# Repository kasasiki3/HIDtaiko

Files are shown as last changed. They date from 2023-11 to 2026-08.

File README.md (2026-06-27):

# HIDtaiko 
#### 低価格で高性能なおうち太鼓プロジェクト
#### HIDtaikoでは[基盤](drumhead/readme_drumhead.md)、[接続器](HIDtaiko_connector_rp2040/rp2040readme.md)の設計を行っています。

[English README](README_EN.md)

 
 
# ◇readme構造
<pre>
.
└── README.md(メイン)
    ├── rp2040readme.md(RP2040接続器の組み立て方、詳細)
    ├── readme_drumhead.md(基盤、詳細)

</pre>

# ◇接続器

> ## [→ RP2040接続器 組み立てガイド](HIDtaiko_connector_rp2040/rp2040readme.md)
> **最新・最安・最高性能のおすすめモデル**（最安800円〜、簡単なはんだ付けのみ）

## 各接続器の比較表
| 項目| 1.2接続器|1.3接続器|2.0接続器| [RP2040接続器](HIDtaiko_connector_rp2040/rp2040readme.md)|
|-----|---|---|---|-----|
| 対応デバイス | PC, Switch | PC| PC, Switch| PC,(switchに対応予定) |
| 感度変更方法 |感度変更サイトで変更可能| 感度変更サイトで変更可能 | 接続器単体で変更可能 | 感度変更サイトで変更可能 |
| ファームウェア | Arduino IDE| Arduino IDE|Arduino IDE| Pico SDK|
| 回路 | 簡易的な1MΩ抵抗| 簡易的な1MΩ抵抗| オペアンプによる信号の増幅| ショットキーバリアダイオードクランプ回路|
| 改造のしやすさ | 簡単| 簡単| 簡単| 難しい|
| 制作難易度 | 中〜高（Arduinoの知識が必要）| 中〜高（Arduinoの知識が必要）| 中〜高（Arduinoの知識が必要）| 低（簡単なはんだ付けのみでOK|
| 制作費用 | 最低構成1500円程度| 最低構成1500円程度| 最低構成2200円程度|最安800円程度|
| 補足 | Switchで使いたい人におすすめ|-|※原因不明の無反応が発生することあり| ※最も新しく、性能も最も高いおすすめモデル |
| プレイ動画 |[動画を見る](https://www.youtube.com/watch?v=cY1Ix29XORo)| [動画を見る](https://www.youtube.com/watch?v=Z8ZBOPpMMD8) | [動画を見る](https://www.youtube.com/watch?v=VVSo0jgkqcQ)| [動画を見る](https://www.youtube.com/watch?v=wMSDLN9h2Co)|

# ◇感度変更サイト

**[→ 感度変更サイトを開く](https://kasasiki3.github.io/HIDtaiko/v12.html)**（Chrome / Edge のみ対応）

接続器を PC に繋いだままブラウザから感度・ディレイを調整できます。V1.1（RP2040）・V1.2 に対応。

## 仕組み

```
ピエゾ → ADC（アナログ読み取り）→ 差分検出 → 閾値判定 → キー入力
```

ピエゾが振動すると電圧が変化します。マイコンは直前サンプルとの差分（デルタ）を計算し、設定した閾値（感度）を超えたときにキー入力を発生させます。

誤検出を防ぐためのタイマー（Delay）も持っており、入力後の一定時間は同センサーや隣接センサーからの入力を無視します。

| パラメータ | 役割 |
|---|---|
| 感度（Sensitivity） | デルタがこの値を超えると入力。値が大きいほど感度が低い |
| Adelay | 同センサーの再入力クールダウン |
| Bdelay | 面（ドン）共有クールダウン |
| Cdelay | 縁（カッ）共有クールダウン |
| Ddelay | 面打後に縁を、縁打後に面を無視する時間 |

# ◇[基盤の作り方](drumhead/readme_drumhead.md)
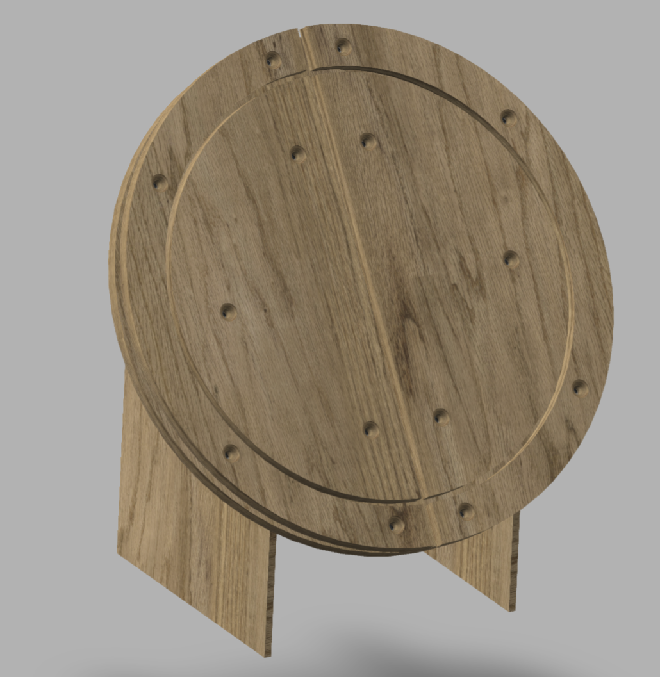
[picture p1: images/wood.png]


## webサイトで基盤のデザインを確認できます:[基盤3Dデータ](https://a360.co/4iZLSSL)

## 基盤の制作方法→記事:[zeen](https://zenn.dev/kasashiki/articles/7bf286b8120f90) 動画:[youtube](https://www.youtube.com/watch?v=5O0MgKzX0PY)

## 特徴
| 項目 | 内容 |
|---|---|
| AC基盤との互換性 | 無 |
| 鉄板・スポンジ・樽| 使用できません |
| 対応面 | AC面・太鼓フォース面|
| 制作所要時間 | 約2〜3時間 |

# ◇センサ
## センサの比較
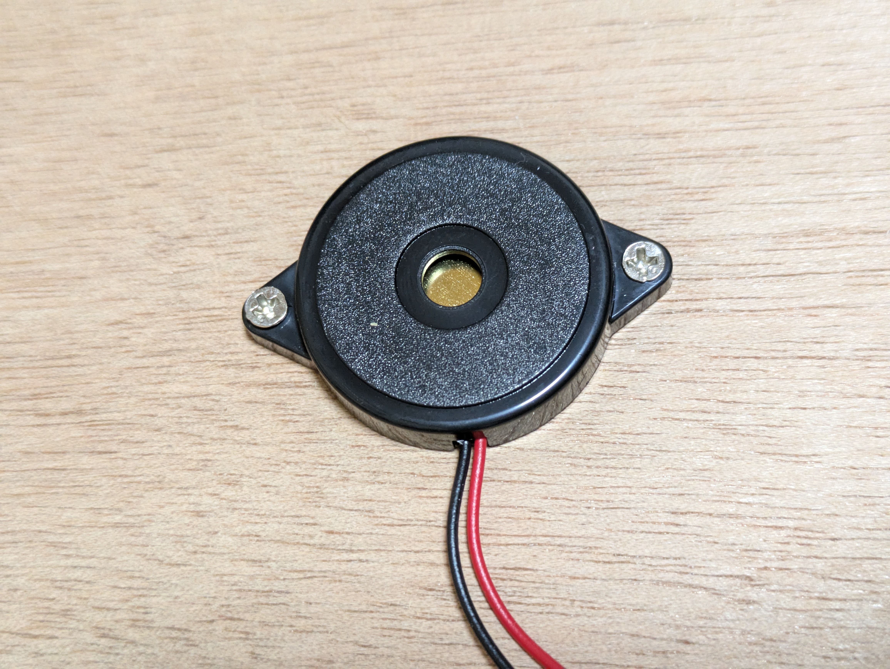
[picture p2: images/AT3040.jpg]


GSS-4SAとAT3040どちらもしっかりと固定することで弱い力でも反応します。しかし、GSS-4SAの方が性能が良いです。設定に余裕が生まれます。価格にかなり差があるため、最初はAT3040センサを購入することをお勧めします。

### [センサ組み立てガイド](drumhead/sensor.md)

# 質問はXのDMにお願いします。
[lit.link](https://lit.link/kasashiki)

## License
*** by kasashiki is licensed under the Apache License, Version2.0

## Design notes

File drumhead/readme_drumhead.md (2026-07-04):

　画像の寸法でベニヤ板をカットし、各ねじを用い組み立てます。組み立ての詳細は[youtube](https://www.youtube.com/watch?v=5O0MgKzX0PY)または[記事(zeen)](https://zenn.dev/kasashiki/articles/7bf286b8120f90)を参照してください。また、販売も行っています。
# 部品
#### ※ラワンベニヤ以外の部品に関してはモノタロウでの購入がおすすめです。
| 部品 | 数量 | 品番|
| ---- | ---- | ---- |
| 防振ゴム | 14 |VD2-2015M6|
| M6ネジ | 14 | [M6L16](https://www.monotaro.com/p/0550/8946/)|
| M6ナット |14 |適当(ネジピッチに注意)|
| M6ワッシャー | 14 |適当|
|ラワンベニヤ | 12mm | ホームセンターなど |  

# 図面
　[A4用紙4を用いた実寸設計図](https://github.com/kasasiki3/HIDtaiko/tree/master/drumhead/fullsizeprint)それぞれのファイルを2枚づつ印刷し、透明なテープで張り合わせてください。


##### 上板の寸法
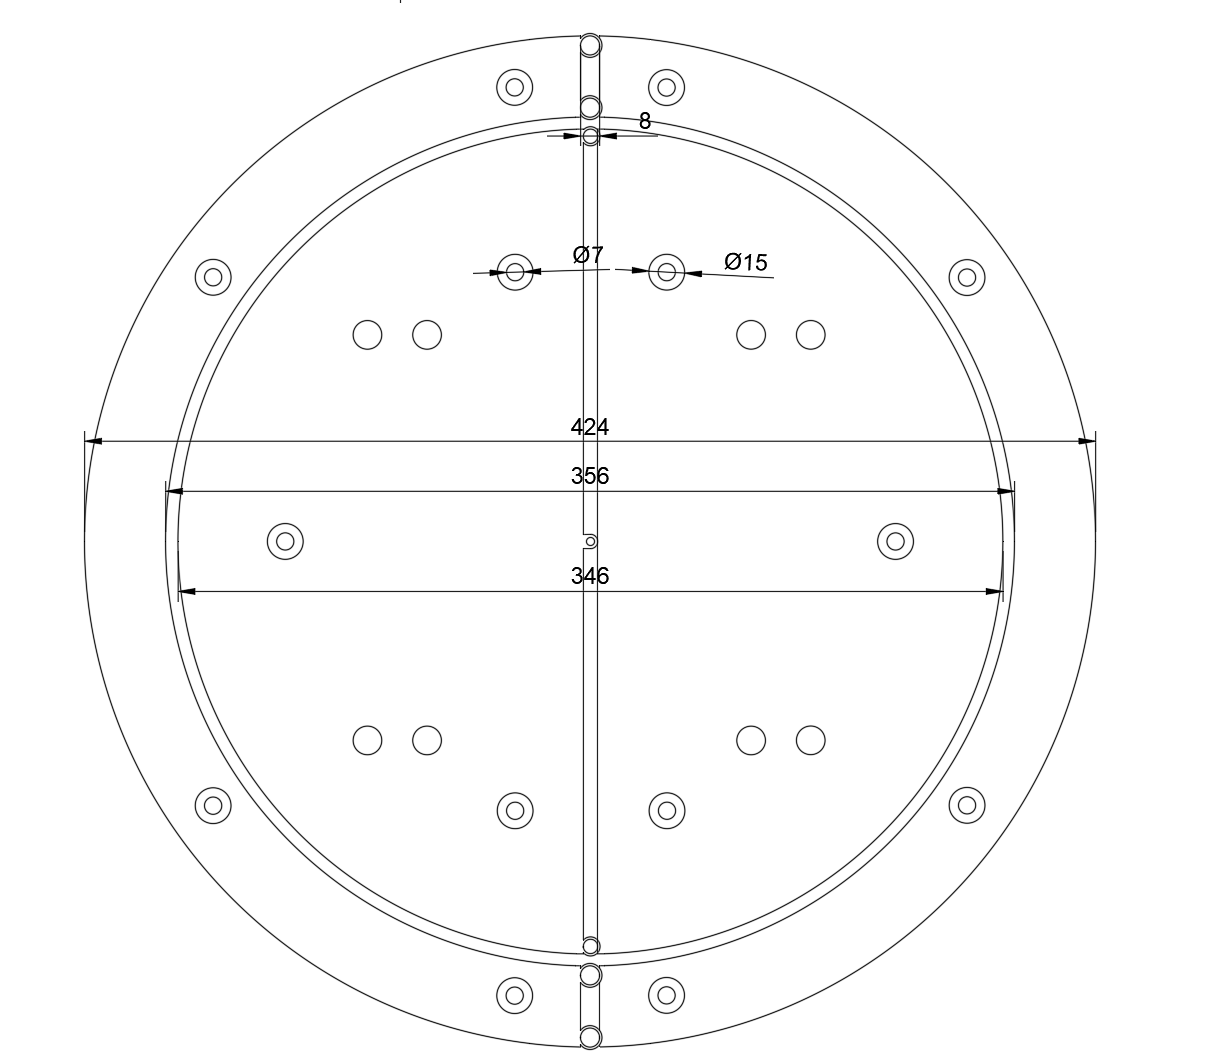
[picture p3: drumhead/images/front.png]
 

 ##### 下板の寸法
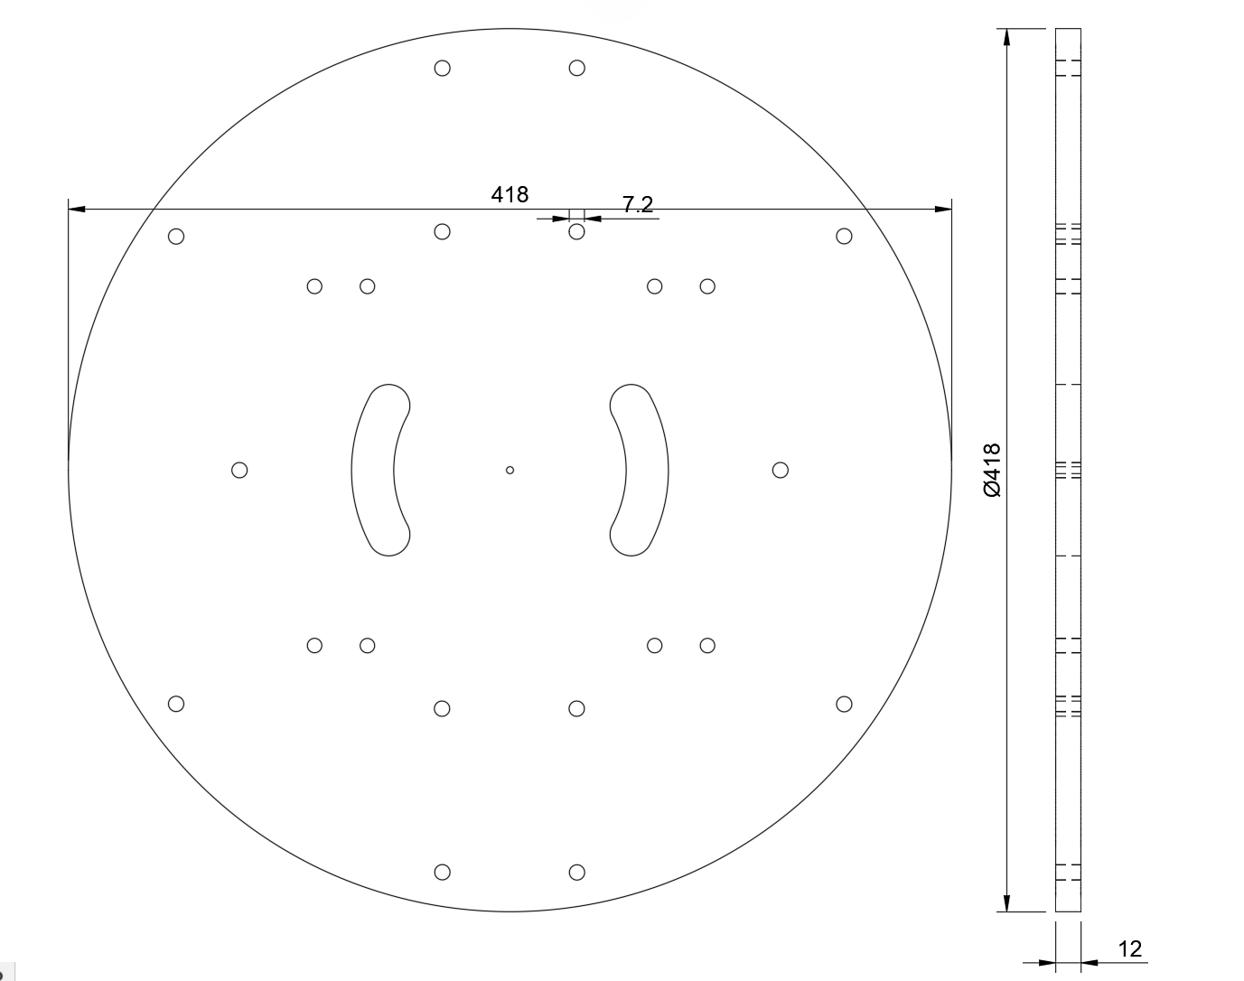
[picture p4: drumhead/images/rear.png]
 

 ##### 足の寸法
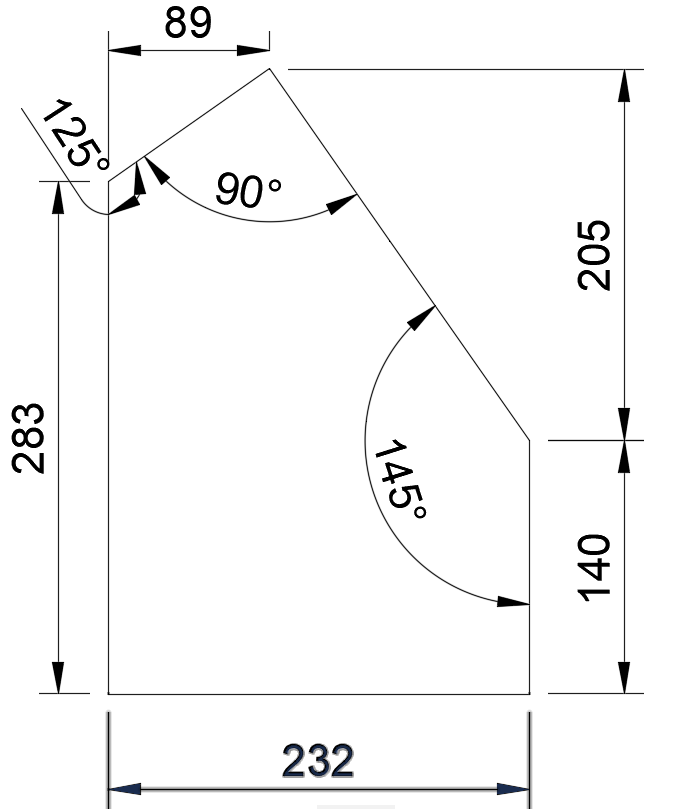
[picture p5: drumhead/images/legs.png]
 

# 3Dプリントパーツ、道具

 ### [面、縁高さ調整用スペーサー(3Dプリント)](spacer) 0.2mm,0.4mm,0.6mm
 
印刷ピッチ0.1～0.2mm、PLAなどで印刷してください。ゴムネジに挟み使用します。

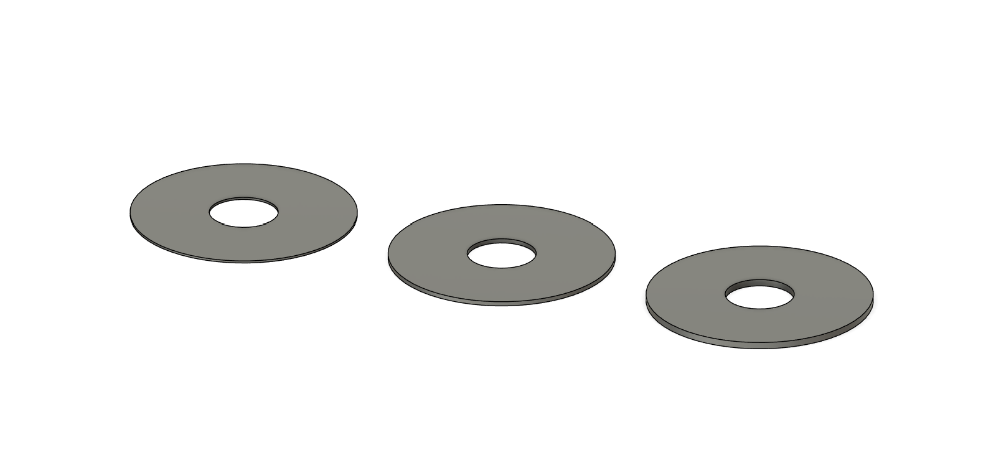
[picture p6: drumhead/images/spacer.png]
  

### [AT3040sensor固定用パーツ(3Dプリント)](AT3040sensor_look)

M3L10ネジを用いて固定します。PLAなどで印刷してください。

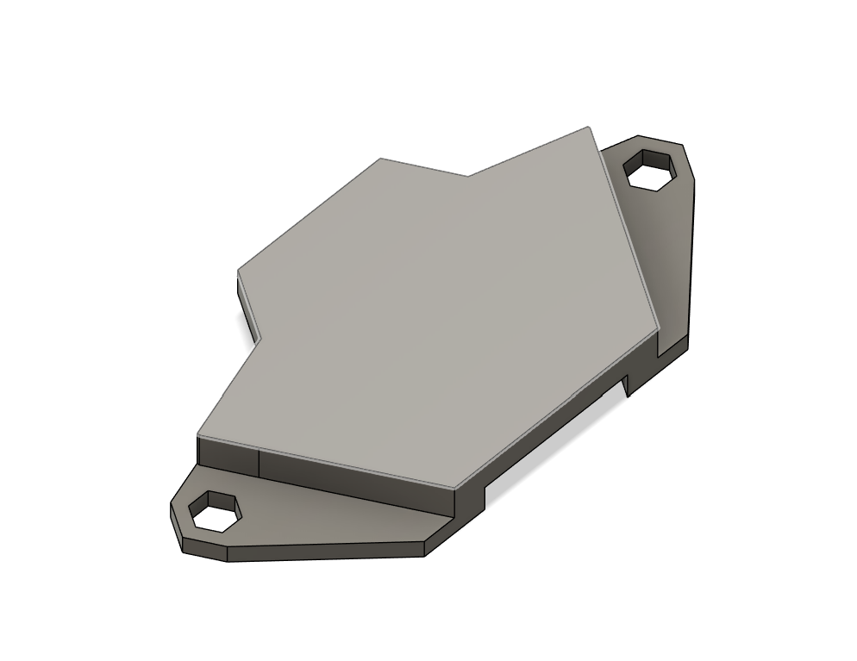
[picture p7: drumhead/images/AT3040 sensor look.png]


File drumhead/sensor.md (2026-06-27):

# 使用するパーツ

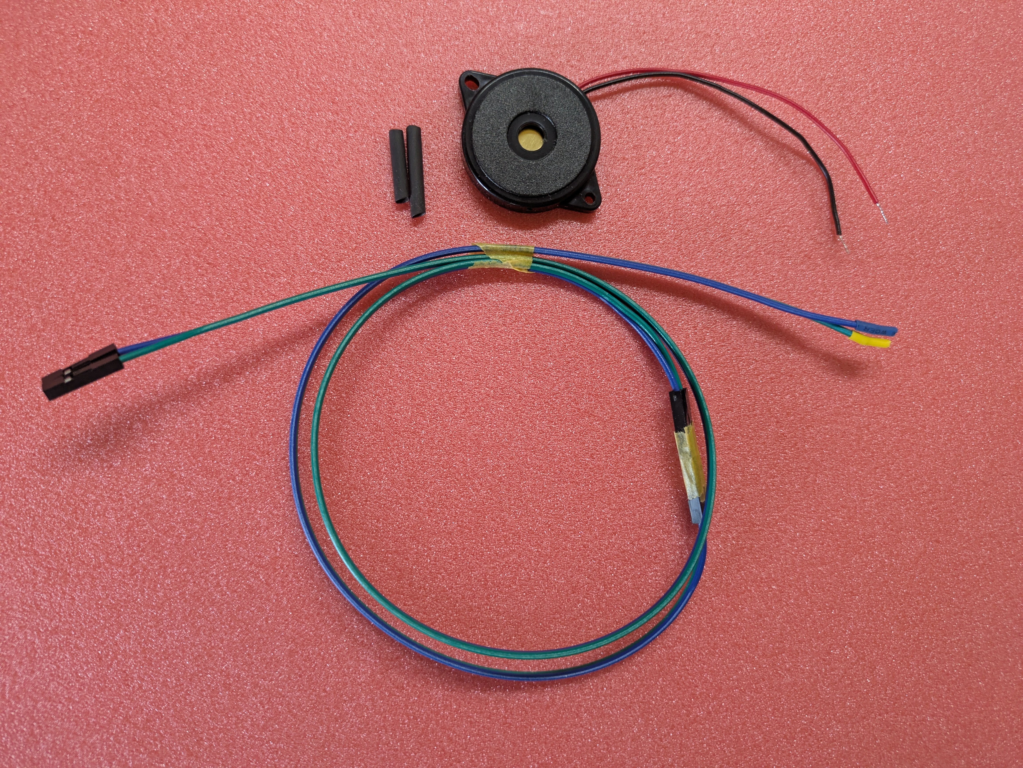
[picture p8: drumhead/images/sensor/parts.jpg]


| 名称 | リンク | 個数 | 合計 |
|---|---|---|---|
| AT3040（センサ） | [aliexpress](https://ja.aliexpress.com/item/1005007327162214.html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) | 5個 | 343円 |
| ケーブル | [aliexpress](https://ja.aliexpress.com/item/1005005364298980.html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) | 1セット | 390円 |
| 熱収縮チューブ(2.5mm)|[aliexpress](https://ja.aliexpress.com/item/1005008597528002.html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)|1|300円|
|固定用M2ネジ|[amazon](https://www.amazon.co.jp/dp/B00AXVBDSO?ref_=ppx_hzsearch_conn_dt_b_fed_asin_title_3)|8本|700円|

# 使用した道具

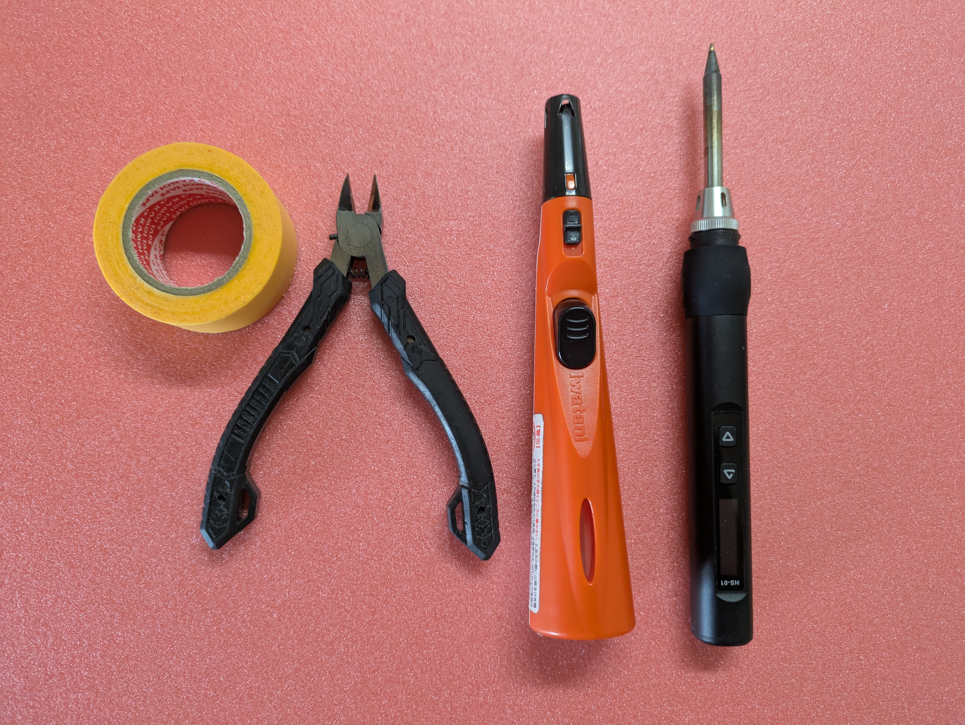
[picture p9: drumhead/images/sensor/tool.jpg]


#### ・はんだごて
#### ・ライター
#### ・ニッパー
#### ・塗装用マスキングテープ

# センサ制作手順

## 1.ケーブルを組み合わせ任意の長さのケーブルを作る

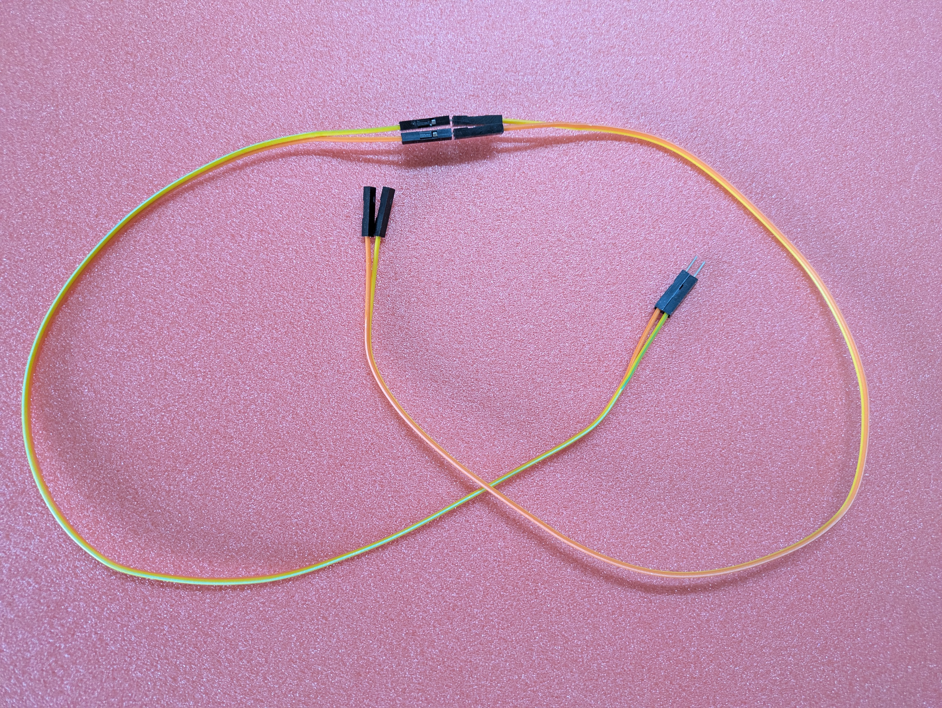
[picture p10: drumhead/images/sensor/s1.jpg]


## 2.接続部を任意の長さで固定する

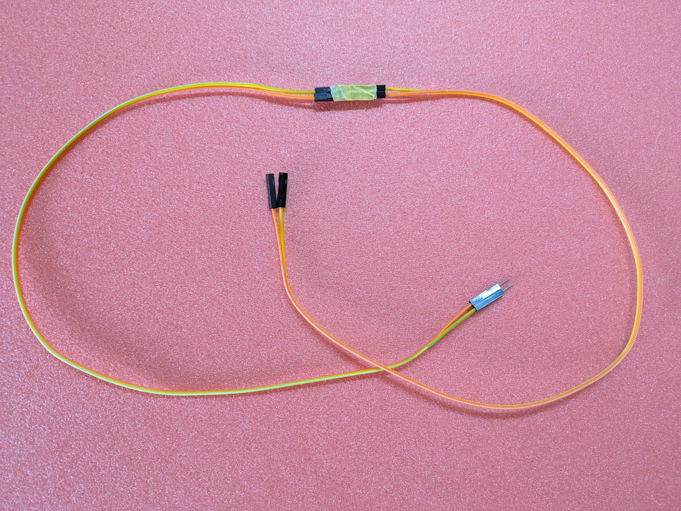
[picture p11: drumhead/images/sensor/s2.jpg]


## 3.オス端子をニッパーで切断する

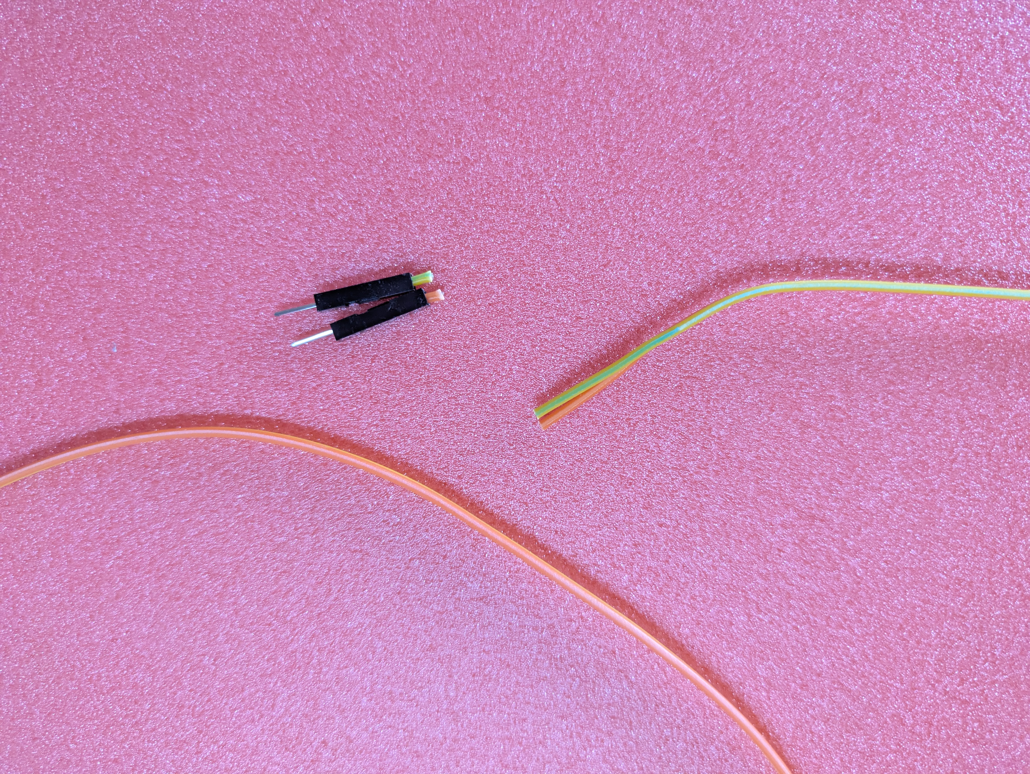
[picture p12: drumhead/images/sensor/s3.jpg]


## 4.ケーブルを剥く(5mm)

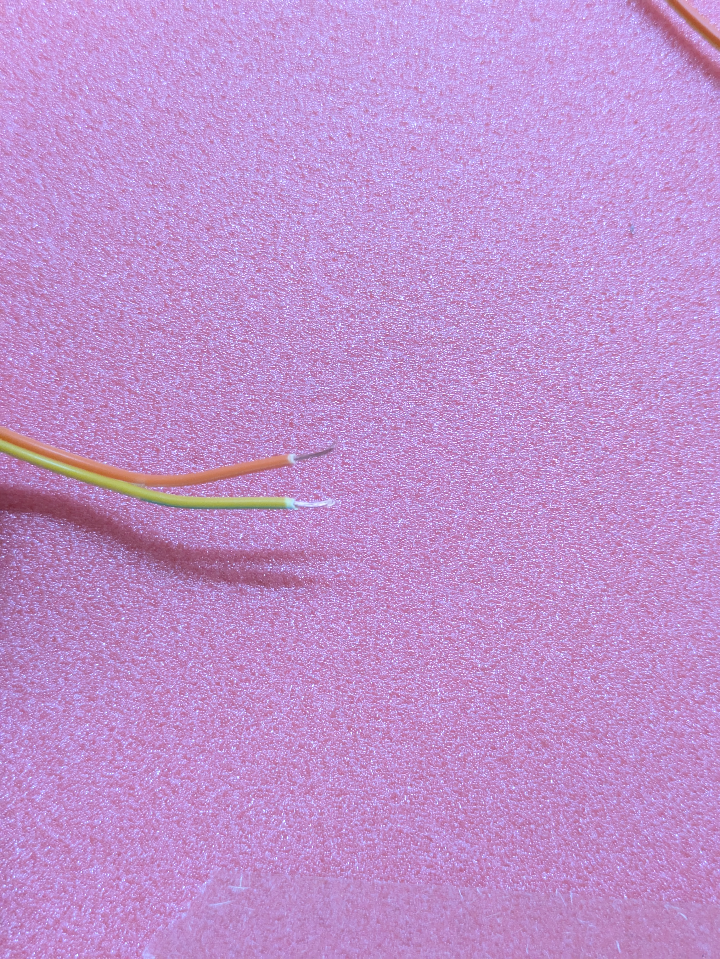
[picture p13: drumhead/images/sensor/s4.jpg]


## 5.露出した銅線に予備ハンダを行う

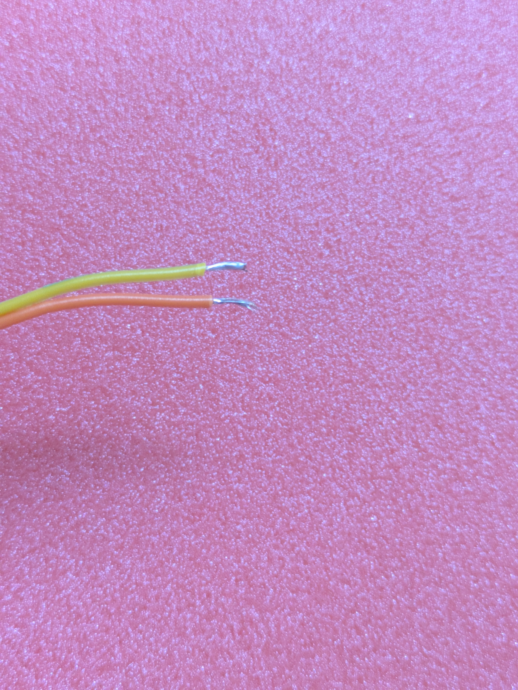
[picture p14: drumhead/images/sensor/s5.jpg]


## 6.センサのケーブルに熱収縮チューブを通す

※熱収縮チューブは10mmにカットしてください。

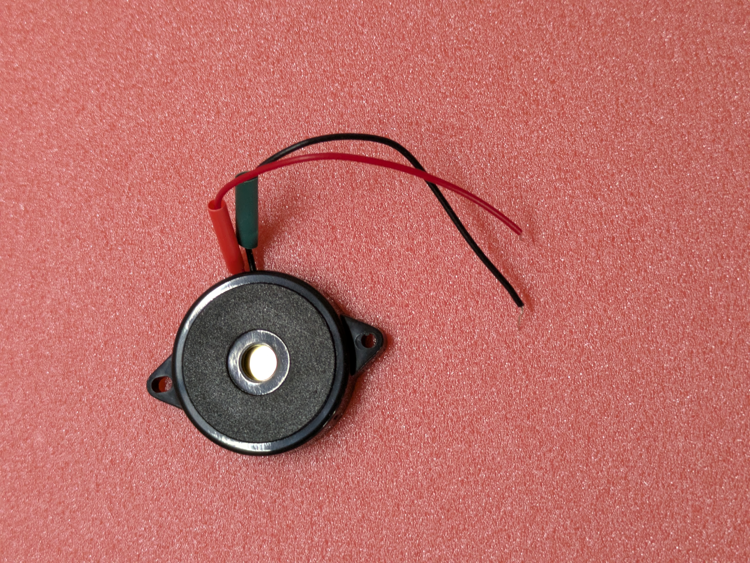
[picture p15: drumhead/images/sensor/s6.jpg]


## 7.ケーブルとセンサをはんだ付けし、しっかりと繋げる

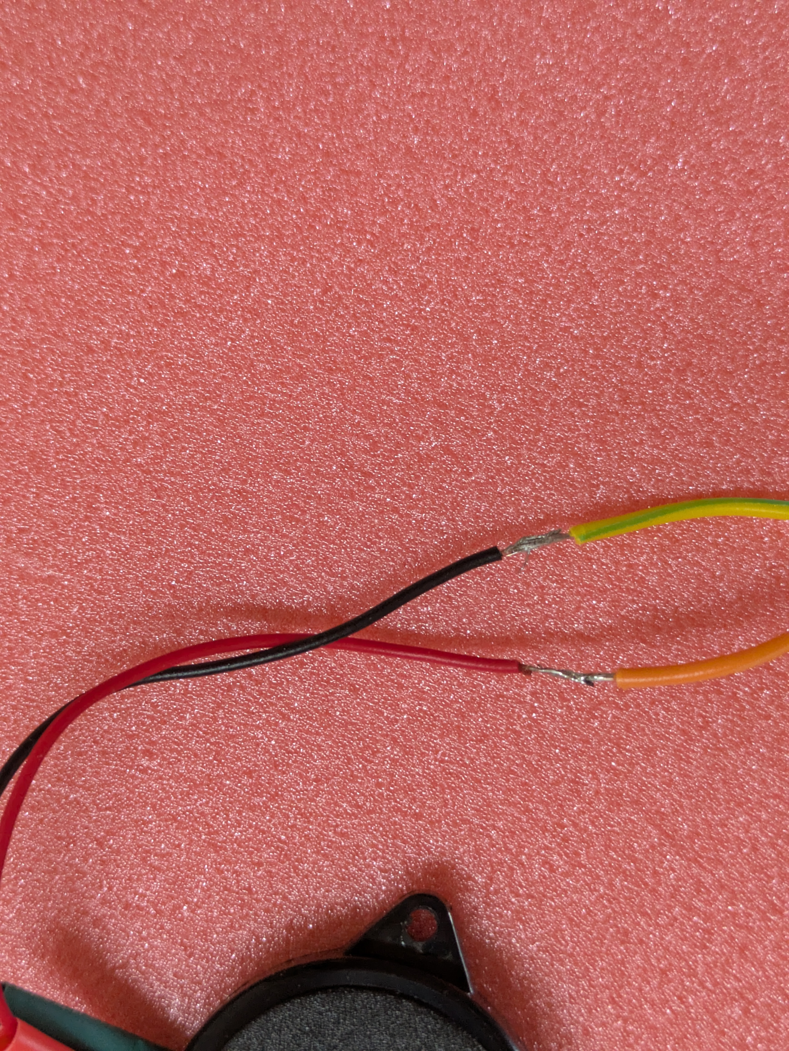
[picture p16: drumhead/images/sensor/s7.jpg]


## 8.熱収縮チューブを加熱し、銅線を保護する

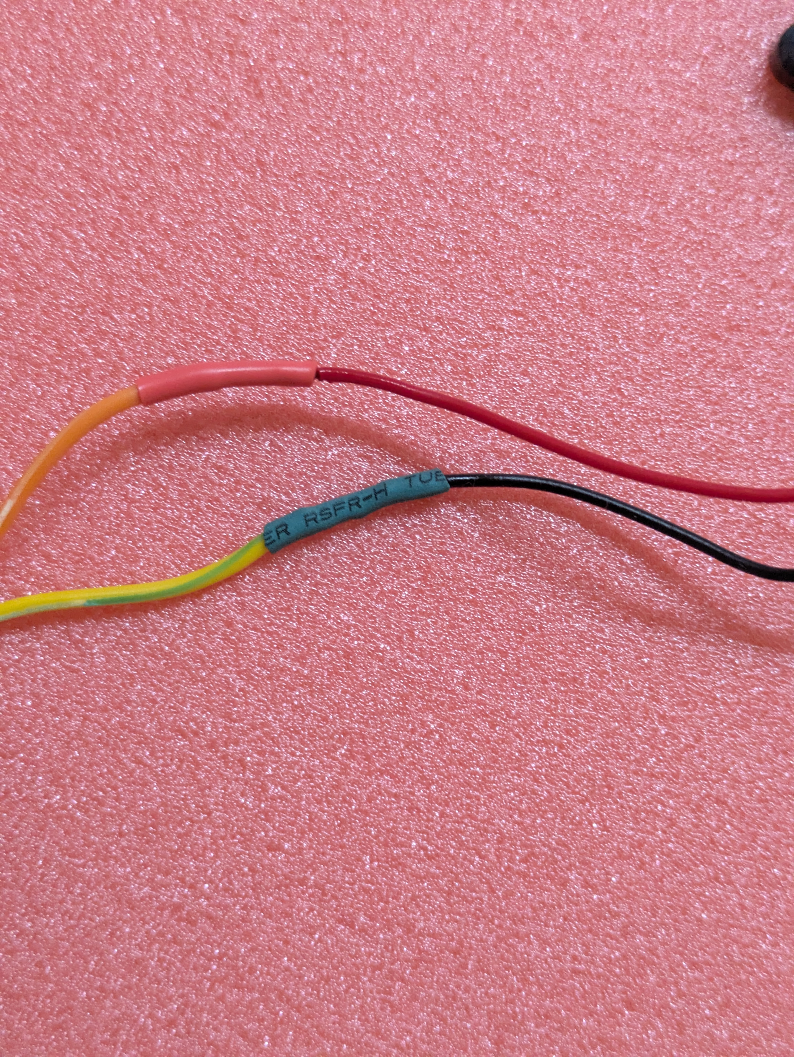
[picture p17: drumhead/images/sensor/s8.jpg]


## 9.この作業を4本分行い、完成

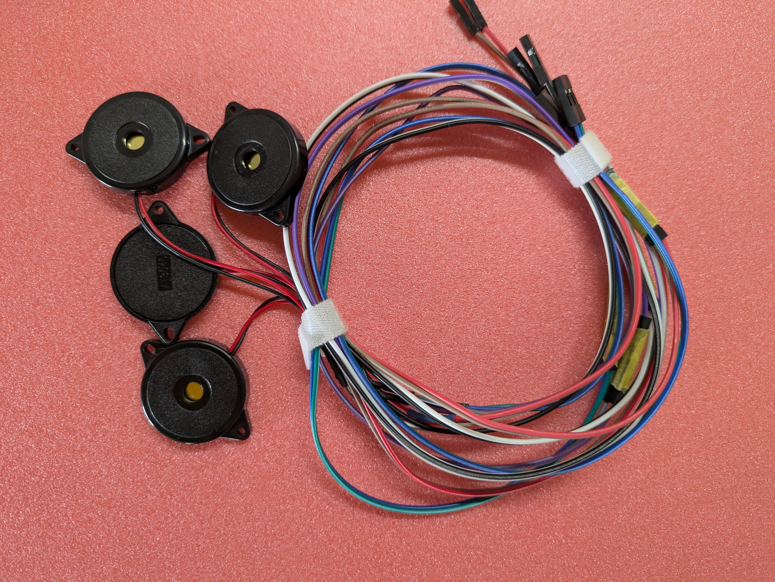
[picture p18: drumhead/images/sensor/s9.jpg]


# 補足

#### ・GSS-4SA（ACセンサ）でも手順は同様です。
#### ・センサの赤いケーブルが＋です。ケーブルの色は以下の画像に合わせることをお勧めします。

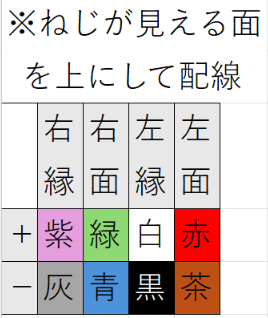
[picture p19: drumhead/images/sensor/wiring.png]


### [AT3040sensor固定用パーツ(3Dプリント)](drumhead/AT3040sensor_look)
センサ固定の際に、こちらを用いることでより確実な固定が可能です。
M3L10ネジを用います。PLAなどで印刷してください。



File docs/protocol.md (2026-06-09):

# HIDtaiko シリアルプロトコル仕様

バージョン: v1.2（ステートレス方式）

---

## 通信方式

- USB CDC シリアル（baud rate: 9600）
- 改行コード: `\n`
- 全コマンドはテキスト形式
- デバイスは全コマンドに対して必ず `OK\n` で応答する

---

## コマンド一覧

### 感度送信 `SENS`

```
JS → device : SENS:0=<v>:1=<v>:2=<v>:3=<v>:4=<v>:5=<v>:6=<v>:7=<v>:8=<v>\n
device → JS : OK\n
```

インデックス対応:

| index | 意味 |
|---|---|
| 0 | 左縁 感度 |
| 1 | 左面 感度 |
| 2 | 右面 感度 |
| 3 | 右縁 感度 |
| 4 | 面入力後の次の入力受付時間 (B) |
| 5 | 縁の入力受付時間 (C) |
| 6 | 面入力時に縁を無視する時間 (D) |
| 7 | シミュレーター用入力制限 (H) |
| 8 | 単体入力受付時間 (A) |

例:
```
SENS:0=80:1=160:2=160:3=80:4=30:5=12:6=35:7=0:8=0
OK
```

---

### 感度要求 `GETS`

```
JS → device : GETS\n
device → JS : 0:<v>\n
              1:<v>\n
              ...
              8:<v>\n
              OK\n
```

例:
```
GETS
0:80
1:160
2:160
3:80
4:30
5:12
6:35
7:0
8:0
OK
```

---

### キー配置送信 `KEY`

```
JS → device : KEY:0=<code>:1=<code>:2=<code>:3=<code>\n
device → JS : OK\n
```

インデックス対応:

| index | 意味 |
|---|---|
| 0 | 左縁 キー |
| 1 | 左面 キー |
| 2 | 右面 キー |
| 3 | 右縁 キー |

値は HID キーコード（例: D=0x07, F=0x09, J=0x0D, K=0x0E）

例:
```
KEY:0=7:1=9:2=13:3=14
OK
```

---

### キー配置要求 `GETK`

```
JS → device : GETK\n
device → JS : 0:<code>\n
              1:<code>\n
              2:<code>\n
              3:<code>\n
              OK\n
```

例:
```
GETK
0:7
1:9
2:13
3:14
OK
```

---

### フラッシュ保存 `SAVE`

```
JS → device : SAVE\n
device → JS : OK\n
```

kando[0..8] と key_map[0..3] を Flash に書き込む。

---

### フラッシュ読み込み `LOAD`

```
JS → device : LOAD\n
device → JS : OK\n
```

Flash から kando[0..8] と key_map[0..3] を読み込む。

---

## フラッシュ格納フォーマット

オフセット `0x1F0000` に `uint16_t` 14個分を書き込む。

| buf16 index | 内容 |
|---|---|
| 0〜8 | kando[0]〜kando[8] |
| 9 | reserved |
| 10〜13 | key_map[0]〜key_map[3] |

key_map の有効範囲チェック: `4 <= v <= 255`（範囲外はデフォルト値を維持）

---

## JS 側の受信方式

`readLine()` で1行ずつ読み出す。内部的に `lineBuffer` に USB CDC パケットを蓄積し、`\n` 単位で切り出す。

要求コマンド（GETS/GETK）は `"OK"` が来るまでループで読み続ける方式のため、行数を事前に知る必要がない。

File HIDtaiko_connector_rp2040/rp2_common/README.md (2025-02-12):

This directory contains libraries specifically targeting the RP2040, RP2350 and possible future related devices.

`hardware_` libraries exist for individual hardware components to provide a simple API
providing a thin abstraction hiding the details of accessing the hardware registers directly.

`pico_` provides higher level functionality you might generally find in say an OS kernel, as well
as runtime support familiar to most C programmers.

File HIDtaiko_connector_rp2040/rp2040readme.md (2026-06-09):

# ◇RP2040接続器ver1.0
#### センサーに1MΩ抵抗を並列に接続した回路です。ver1.1には性能、安定感でやや劣りますが、回路がシンプルになります。
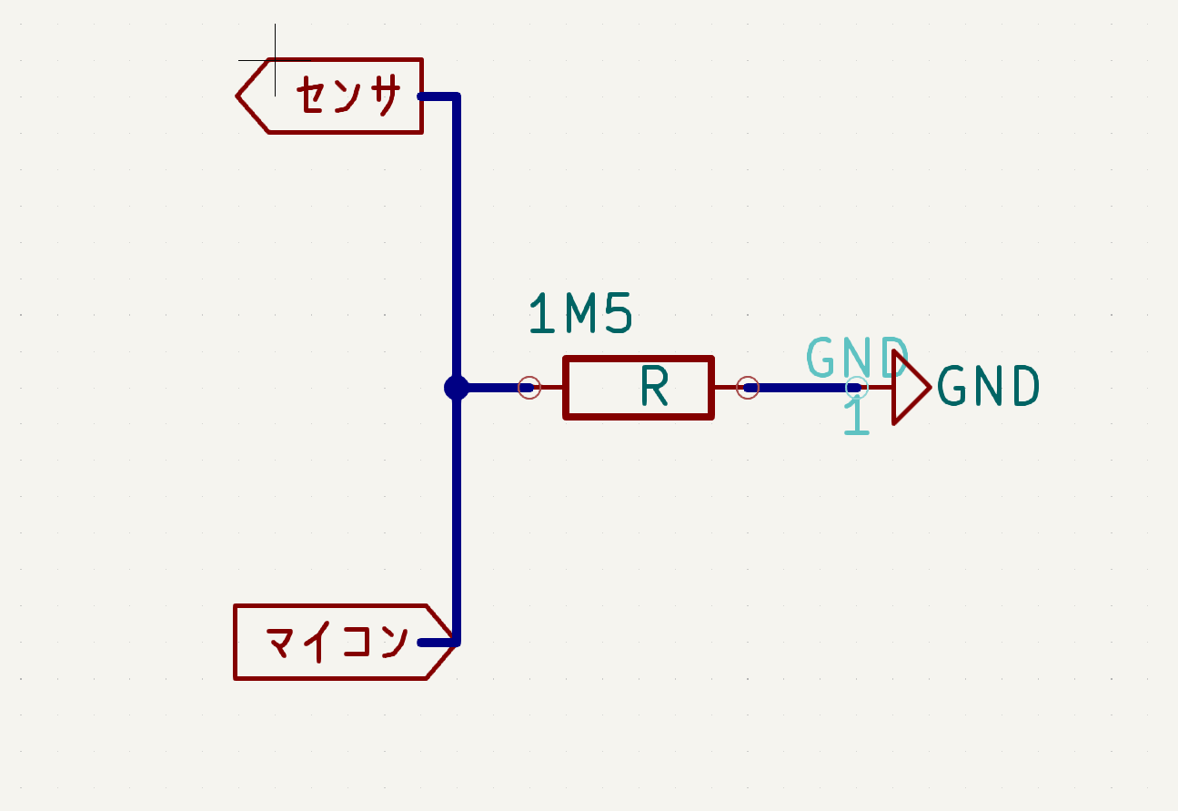
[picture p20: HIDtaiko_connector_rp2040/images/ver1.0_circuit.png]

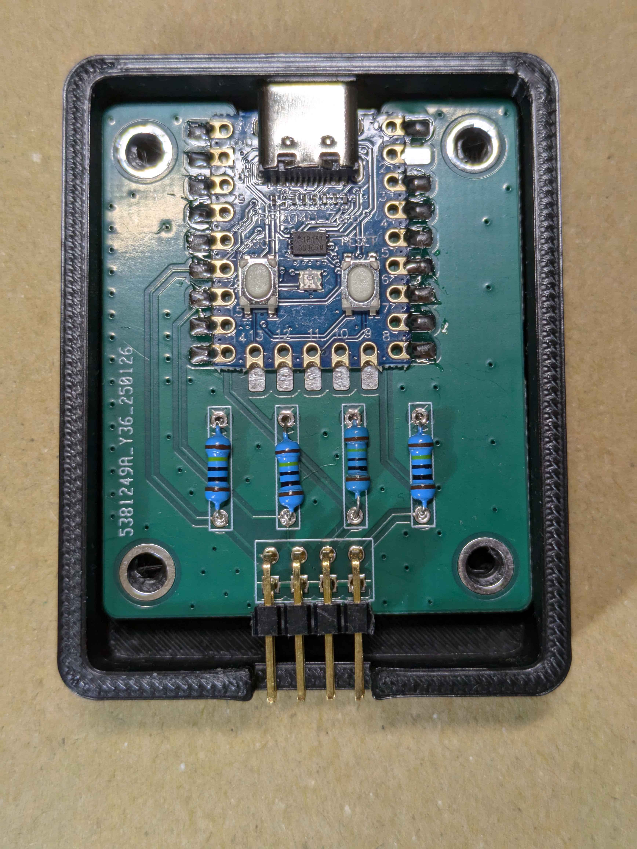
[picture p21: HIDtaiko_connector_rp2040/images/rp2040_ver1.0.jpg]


### 部品表
#### [制作ガイド](https://zenn.dev/kasashiki/articles/28d31814b8bf86)
| 部品 | 数量 | リンク |
| ---- | ---- | ---- |
| rp2040zero | 1 | [adcpinが4つある物](https://ja.aliexpress.com/item/1005005407839815.html) |
| 1/4W1M1Ω抵抗 | 4 | [抵抗セット](https://www.amazon.co.jp/dp/B0CT8PJ97X) |
| 4×2のピンヘッダ | 1 | [L字ピンヘッダ](https://www.amazon.co.jp/dp/B00TRTIB7O) |
| 基板 | 1 | [ブレットボード基板](https://www.amazon.co.jp/dp/B0CMHD34G6) |
| M3×5mmネジ | 4 | [ねじセット](https://www.amazon.co.jp/dp/B09SCV6HL5) |
| 3Dプリントケース | 1 | [stlファイル](https://github.com/kasasiki3/HIDtaiko/tree/master/HIDtaiko_connector_rp2040/case) |

### 性能
※一部のシュミレーターでは入力制限を入れないとキー入力が認識されない可能性があるため、この性能が出ません。

・ドカ、カド処理含め、すべてのロール処理が入ります

・ロール連打(一振り):13

・旧ダブル連打(ドキムネ):1000

#### [プレイ動画](https://www.youtube.com/watch?v=6kISQiHiIU8&t=2s)

# ◇RP2040接続器ver1.1

#### vショットキーバリアダイオードを用いたクランプ回路を追加し、性能、安定感が向上しました。
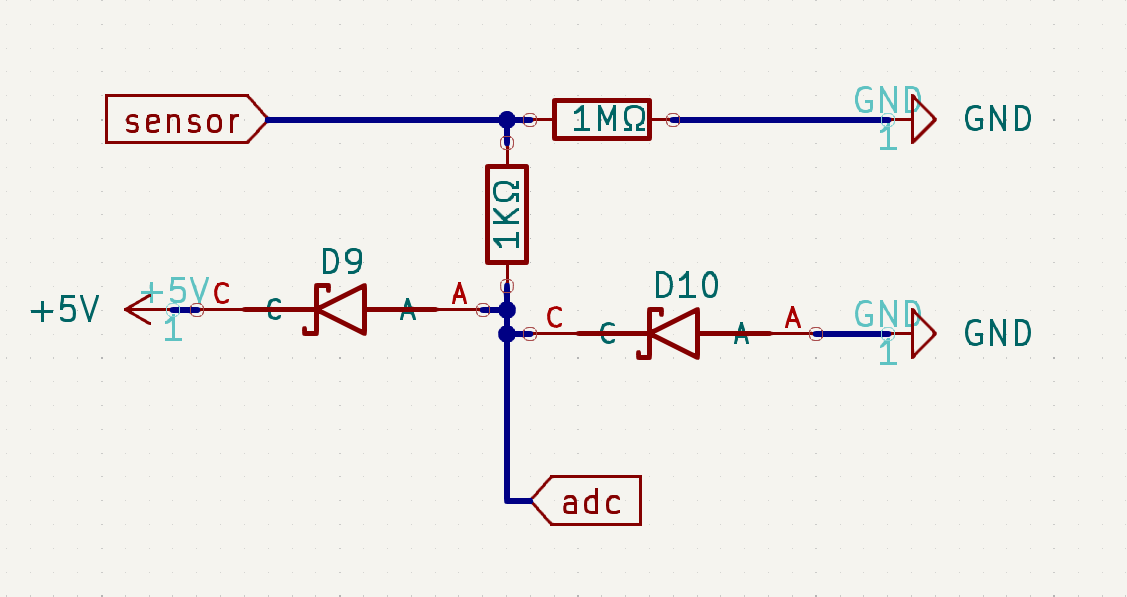
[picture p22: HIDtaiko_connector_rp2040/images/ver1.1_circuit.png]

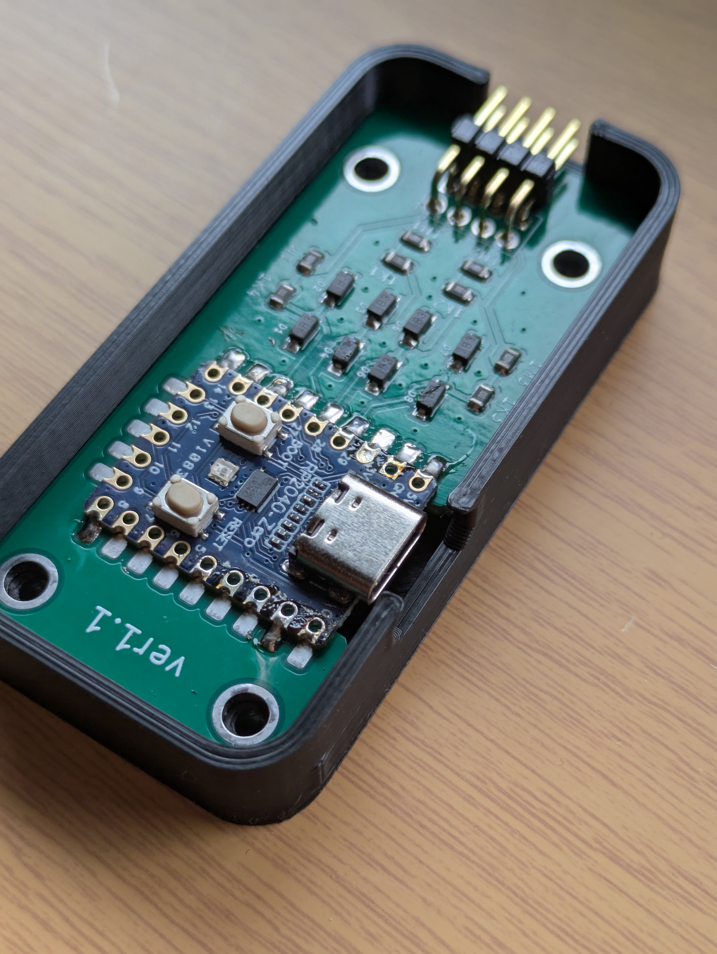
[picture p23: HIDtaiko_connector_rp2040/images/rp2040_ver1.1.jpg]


### 部品表
| 部品 | 数量 | リンク |
| ---- | ---- | ---- |
| rp2040zero | 1 | [adcpinが4つある物](https://ja.aliexpress.com/item/1005005407839815.html) |
| 1M1Ω抵抗 | 4 | [抵抗セット](https://www.amazon.co.jp/dp/B0CT8PJ97X) |
| ショットキーバリアダイオード | 8 | [動作確認済の物](https://ja.aliexpress.com/item/1005001552094086.html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) |
| 1KΩ抵抗 | 4 | [抵抗セット](https://www.amazon.co.jp/dp/B0CT8PJ97X) |
| 4×2のピンヘッダ | 1 | [L字ピンヘッダ](https://www.amazon.co.jp/dp/B00TRTIB7O) |
| 基板 | 1 | [ブレットボード基板](https://www.amazon.co.jp/dp/B0CMHD34G6) |
| M3×5mmネジ | 4 | [ねじセット](https://www.amazon.co.jp/dp/B09SCV6HL5) |
| 3Dプリントケース | 1 | [stlファイル](https://github.com/kasasiki3/HIDtaiko/tree/master/HIDtaiko_connector_rp2040/case) |

### 性能
※一部のシュミレーターでは入力制限を入れないとキー入力が認識されない可能性があるため、この性能が出ません。

・ドカ、カド処理含め、すべてのロール処理が入ります

・ロール連打(一振り):13

・旧ダブル連打(ドキムネ):1200

#### [プレイ動画](https://www.youtube.com/watch?v=wMSDLN9h2Co)

# rp2040zero接続器作り方

## ◇はじめに
#### ・この解説ははんだ付けの知識、簡単な回路図を読む力が必要です。もし不明な点がありましたらDMにて質問してください。
#### ・完成品はメルカリにて販売しています。[(メルカリ)](https://jp.mercari.com/user/profile/175469287)
#### ・はんだごて、ニッパーが必要です。
#### ・

## ◇使用する部品


### 部品表
| 部品 | 数量 | リンク |
| ---- | ---- | ---- |
| rp2040zero | 1 | [adcpinが4つある物](https://ja.aliexpress.com/item/1005005407839815.html) |
| 1M1Ω抵抗 | 4 | [抵抗セット](https://www.amazon.co.jp/dp/B0CT8PJ97X) |
| ショットキーバリアダイオード | 8 | [動作確認済の物](https://ja.aliexpress.com/item/1005001552094086.html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) |
| 1KΩ抵抗 | 4 | [抵抗セット](https://www.amazon.co.jp/dp/B0CT8PJ97X) |
| コネクタ | 1 | [L字ピンヘッダ](https://www.amazon.co.jp/dp/B00TRTIB7O) |
| 基板 | 1 | [基板](https://ja.aliexpress.com/item/1005007024264426.html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) |
| ジャンパーワイヤー | (任意) | [セット](https://ja.aliexpress.com/item/1005006014728282.html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) |

## ◇回路図、組み立て例
#### 配線の形は自由です。これは例です。RP2040zeroのGPIOpinを確認しながら間違わないようにに配線してください。

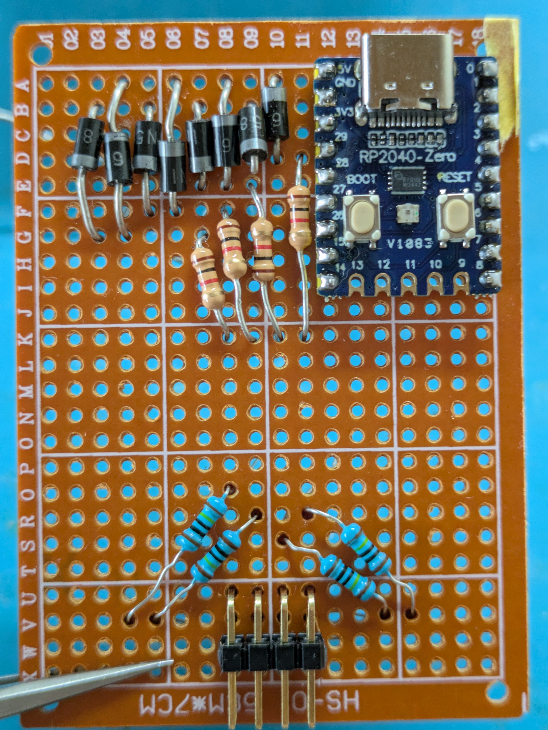
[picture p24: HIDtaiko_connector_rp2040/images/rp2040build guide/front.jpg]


回路全体

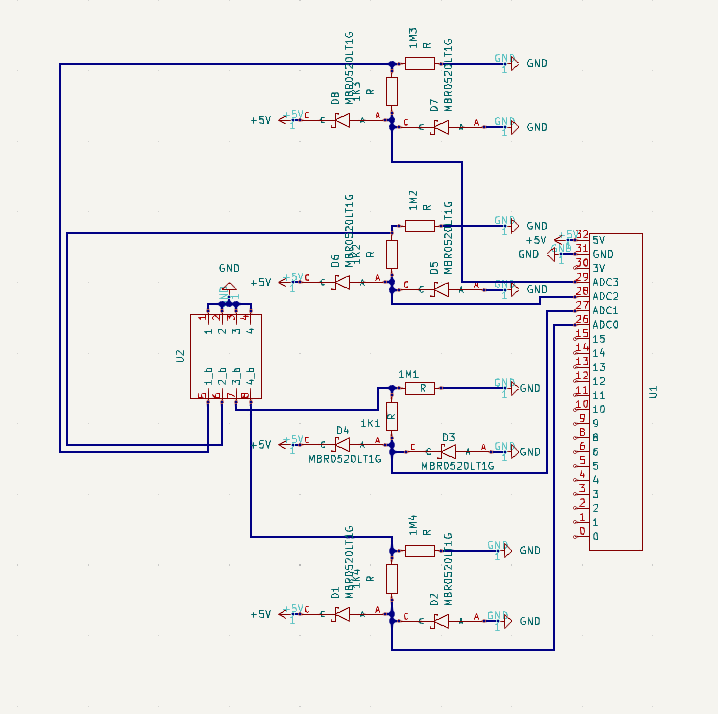
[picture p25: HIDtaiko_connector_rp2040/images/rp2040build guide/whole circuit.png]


この回路を4つ用意します。



## ◇rp2040zeroをハンダ付け
#### まずはピンヘッダをrp2040zero固定します。

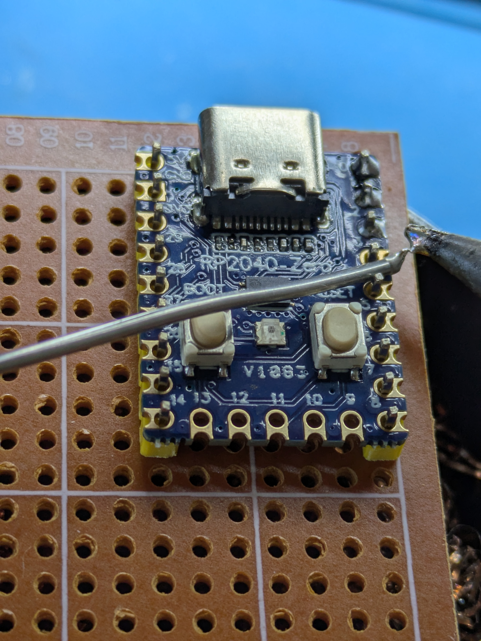
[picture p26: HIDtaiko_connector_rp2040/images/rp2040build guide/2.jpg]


#### 次に基板に固定します。



## ◇コネクタの取付

#### 基板に対して並行になるように調整してください。





## ◇その他の電子部品の取付




#### 回路を理解し、部品を配置してください。
#### 部品を配置したら、まずは部品を基板にハンダ付けしてください。
#### その後、電子部品のピンを倒し、配線を行ってください。



## ◇ファームウェア書き込み

#### [ファームウェア](original_uf2/hidtaiko.uf2)をダウンロードし、エクスプローラーで開いてください。
#### 次に、このボタンを押しながらUSBケーブルでPCに接続します



#### ストレージとして認識されるのでファームウェアをドラック＆ドロップで入れます。

## ◇感度変更

[感度変更アプリ](https://kasasiki3.github.io/ver1.3_webapp_rp2040version/)こちらにアクセスし、基本の感度を接続器に送ってください。

#### 入力が出来たら完成です。

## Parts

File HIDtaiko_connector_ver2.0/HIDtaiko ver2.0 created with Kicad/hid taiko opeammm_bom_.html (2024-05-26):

Source File | hid taiko opeammm.kicad_sch
BoM Date | 2024/05/11 1:32:42
Schematic Version
Schematic Date
PCB Variant | default
KiCad Version | Eeschema 7.0.9
Component Groups | 12
Component Count (per PCB) | 33
Fitted Components (per PCB) | 33
Number of PCBs | 1
Total Component Count (for 1 PCBs) | 33
 | Description | Part | References | Value | Footprint | Quantity Per PCB | Datasheet | Sim.Device | Sim.Library | Sim.Name | Sim.Params | Sim.Pins
1 | Voltage dependent resistor | Varistor | 10k1 10k2 10k3 10k4 | Varistor | 3362P | 4 | ~ | SUBCKT | ${KICAD7_SYMBOL_DIR}/Simulation_SPICE.sp | kicad_builtin_varistor | threshold=1k | 1=A 2=B
2 | SSD1306 OLED | SSD1306 | Brd1 | SSD1306 | 128x64OLED2 | 1
3 | Unpolarized capacitor | C | C1 C2 | C | capacitor 3mm | 2 | ~
4 | Generic connector, single row, 01x02, script generated | Conn_01x02_Pin | J1 J2 J3 J4 | Conn_01x02_Pin | 2pin | 4 | ~
5 | Resistor | R | R1 R3 R4 R5 R7 R10 R11 R12 | 10k | R_0805_2012Metric | 8 | ~
6 | Resistor | R | R2 R6 R8 R9 | R | R_0805_2012Metric | 4 | ~
7 | Rotary encoder, dual channel, incremental quadrate outputs | RotaryEncoder | SW1 | RotaryEncoder | RotaryEncoder_Alps_EC12E-Switch_Vertical_H20mm | 1 | ~
8 | Push button switch, generic, two pins | SW_Push | SW3 SW4 SW5 SW6 | SW_Push | Kailh_Choc_V1 | 4 | ~
9 | Push button switch, generic, two pins | SW_Push | SW7 | SW_Push | SW_PUSH_6x3mm | 1 | ~
10 | Switch, single pole double throw | SW_SPDT_321 | SW2 | SW_SPDT_321 | SS12D00G3 | 1 | ~
11 |  | LM358N_NOPB | U2 U3 | LM358N/NOPB | NJR-SOP8_NJR | 2 | LM358N/NOPB
12 |  | BrownSugar_KBD_ProMicro | U1 | ProMicro | ProMicro | 1

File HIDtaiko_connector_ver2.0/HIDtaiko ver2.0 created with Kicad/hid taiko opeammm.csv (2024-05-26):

# | Reference | Qty | Value | Footprint | DNP
1 | 10k1, 10k2, 10k3, 10k4 | 4 | Varistor | Library 自作:3362P
2 | Brd1 | 1 | SSD1306 | Library 自作:128x64OLED2
3 | C1, C2 | 2 | C | Library 自作:capacitor 3mm
4 | J1, J2, J3, J4 | 4 | Conn_01x02_Pin | Library 自作:2pin
5 | R1, R3, R4, R5, R7, R10, R11, R12 | 8 | 10k | Resistor_SMD:R_0805_2012Metric
6 | R2, R6, R8, R9 | 4 | R | Resistor_SMD:R_0805_2012Metric
7 | SW1 | 1 | RotaryEncoder | Rotary_Encoder:RotaryEncoder_Alps_EC12E-Switch_Vertical_H20mm
8 | SW2 | 1 | SW_SPDT_321 | Library 自作:SS12D00G3
9 | SW3, SW4, SW5, SW6 | 4 | SW_Push | keyboard:Kailh_Choc_V1
10 | SW7 | 1 | SW_Push | keyboard:SW_PUSH_6x3mm
11 | U1 | 1 | ProMicro | keyboard:ProMicro
12 | U2, U3 | 2 | LM358N/NOPB | Library opeanpu:NJR-SOP8_NJR

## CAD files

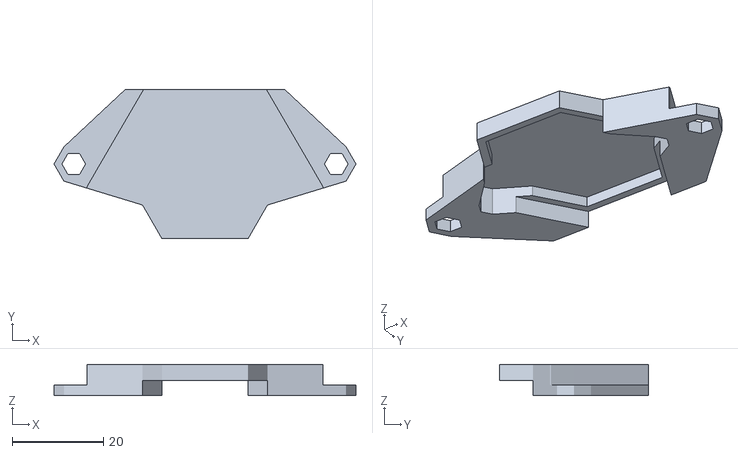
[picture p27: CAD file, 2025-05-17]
drumhead/AT3040sensor_look/at3040sensor lock.stl
66.2 x 32.7 x 6.80

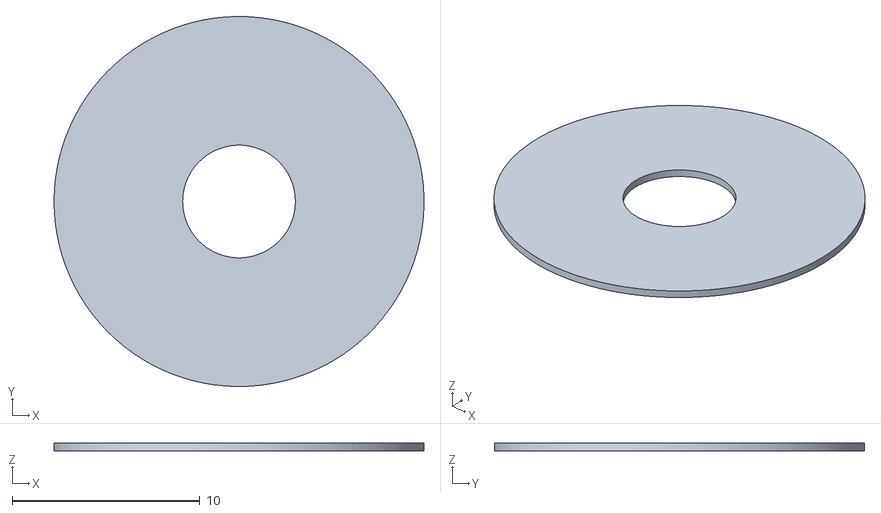
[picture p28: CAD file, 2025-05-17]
drumhead/spacer/0.4.stl
19.7 x 19.7 x 0.4

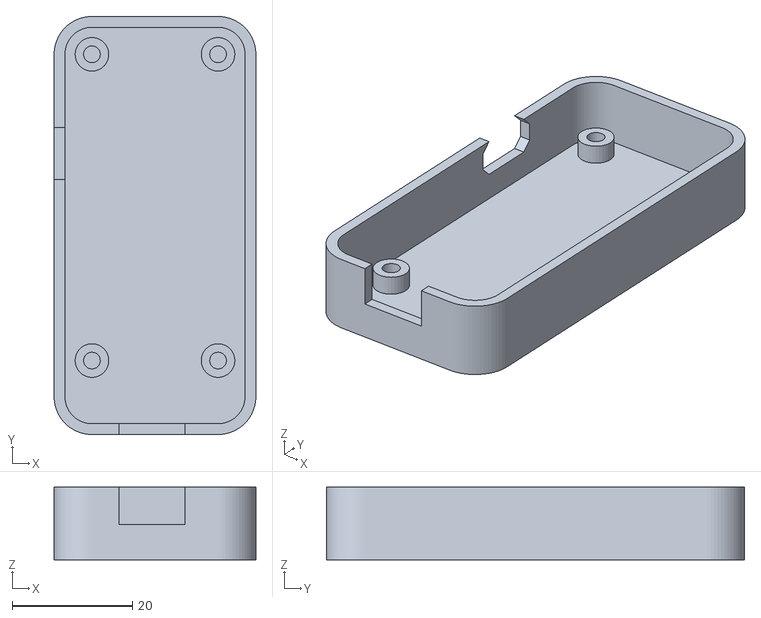
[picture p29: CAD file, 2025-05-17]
HIDtaiko_connector_rp2040/case/ver1.1/case.stl
33.6 x 69.6 x 12.1

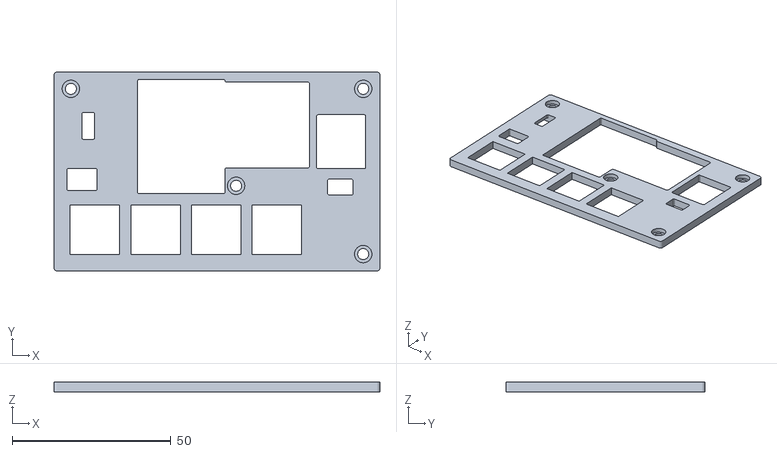
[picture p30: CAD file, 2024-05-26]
HIDtaiko_connector_ver2.0/case/ver2.0 plate.stl
102.6 x 62.6 x 3.00

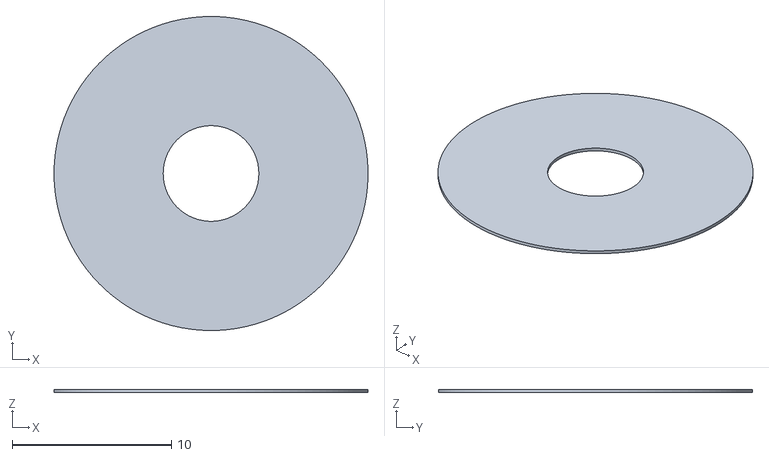
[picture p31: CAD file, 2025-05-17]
drumhead/spacer/0.2.stl
19.7 x 19.7 x 0.2

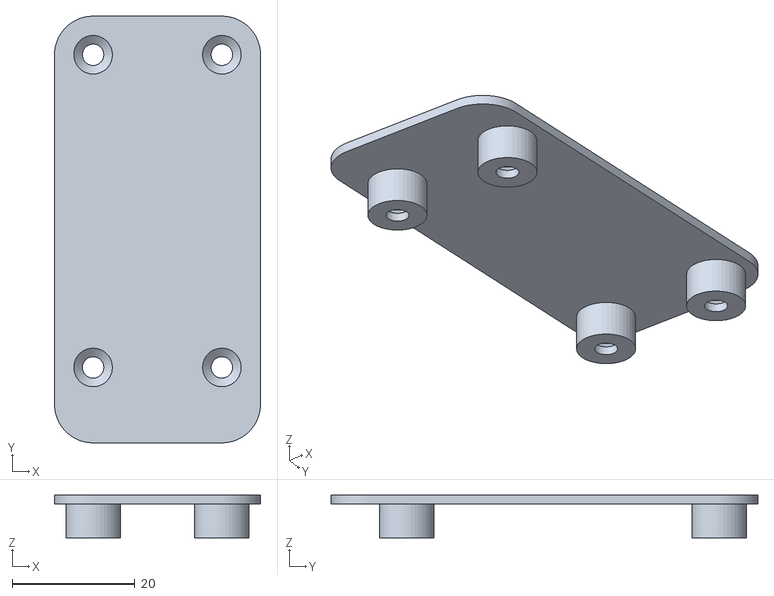
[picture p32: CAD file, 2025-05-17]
HIDtaiko_connector_rp2040/case/ver1.1/lid.stl
33.6 x 69.6 x 7.00

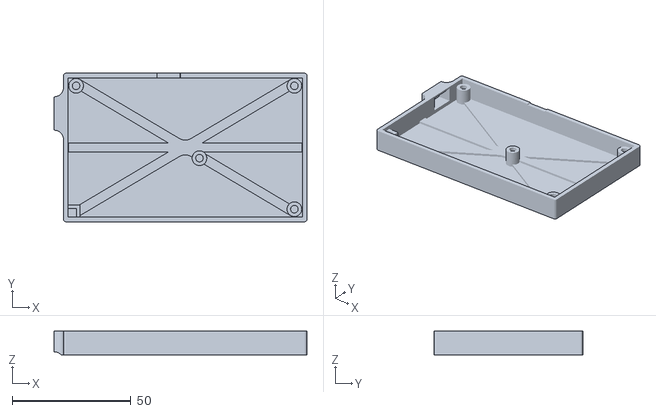
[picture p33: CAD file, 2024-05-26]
HIDtaiko_connector_ver2.0/case/ver2.0 case.stl
106.6 x 62.6 x 10.00

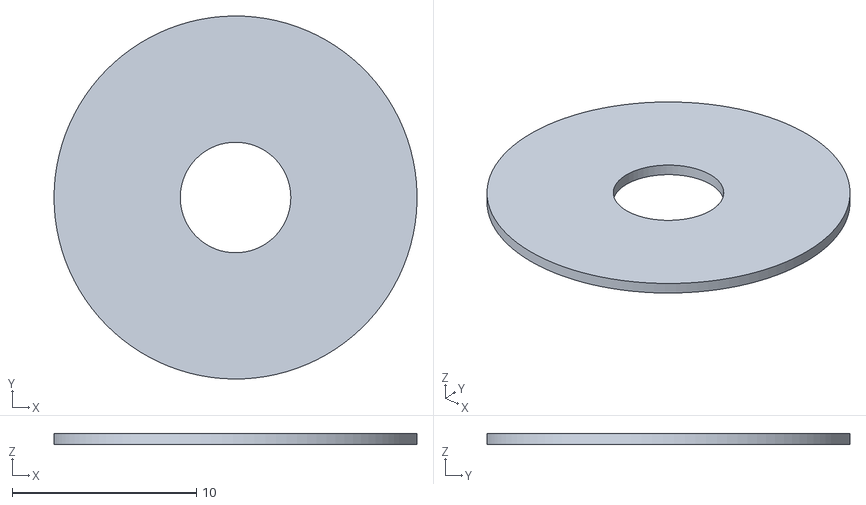
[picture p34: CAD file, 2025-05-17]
drumhead/spacer/0.6.stl
19.7 x 19.7 x 0.6

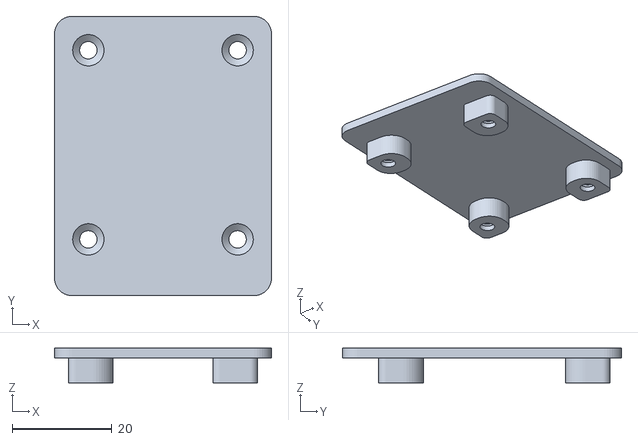
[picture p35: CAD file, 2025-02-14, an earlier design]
HIDtaiko_connector_rp2040/case/ver1.0/lib_rp.stl
43.6 x 56.1 x 7.00

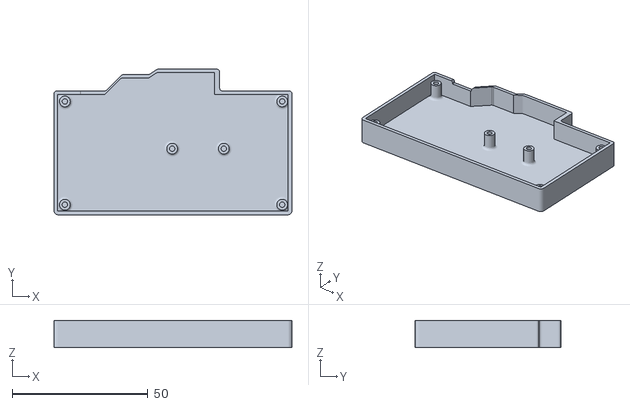
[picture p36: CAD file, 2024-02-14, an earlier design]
HIDtaiko_connector_ver1.2/case.stl
87.6 x 53.6 x 10.0

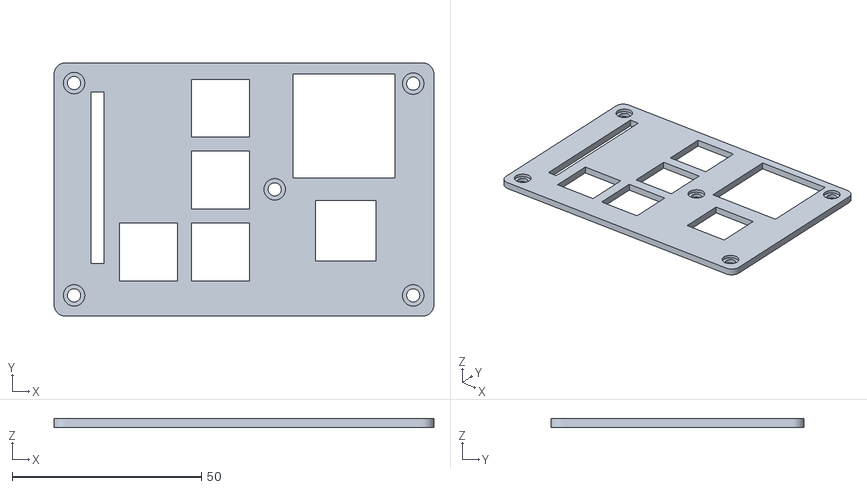
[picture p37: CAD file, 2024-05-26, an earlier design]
HIDtaiko_connector_ver1.2/case.ver.2.0/ボディ2.stl
100.5 x 67.0 x 2.30

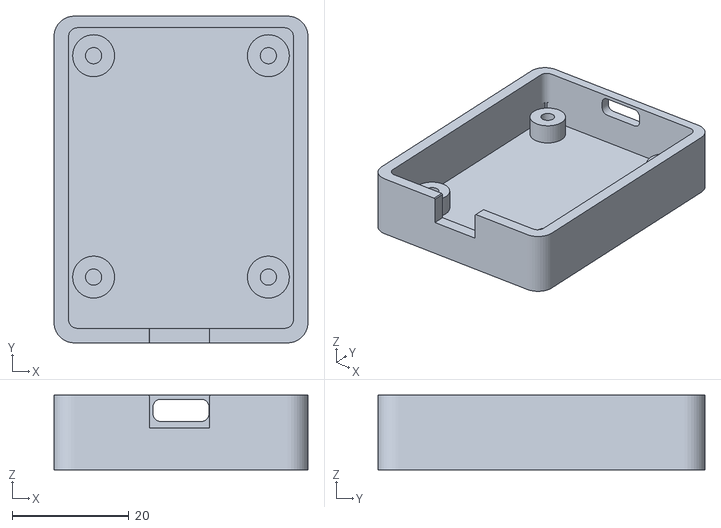
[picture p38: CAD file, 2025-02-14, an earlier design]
HIDtaiko_connector_rp2040/case/ver1.0/case_rp.stl
43.6 x 56.1 x 12.8

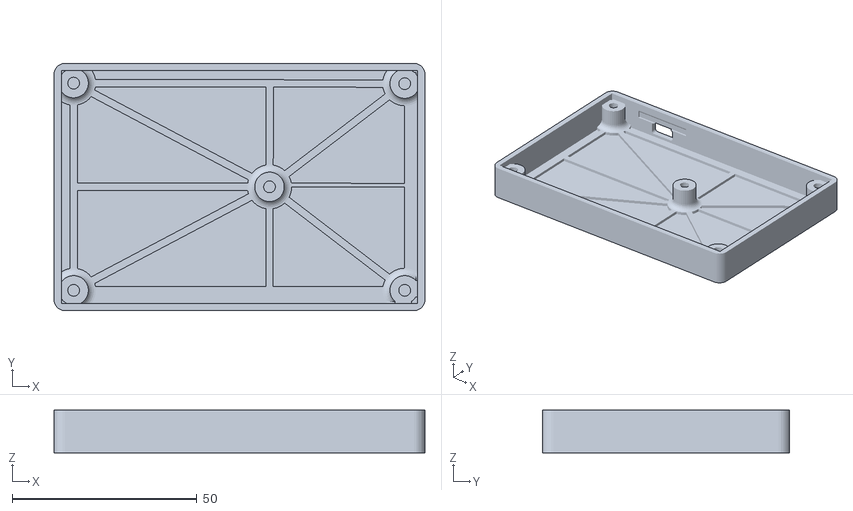
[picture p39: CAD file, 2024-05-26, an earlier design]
HIDtaiko_connector_ver1.2/case.ver.2.0/ボディ1.stl
100.5 x 67.0 x 11.6

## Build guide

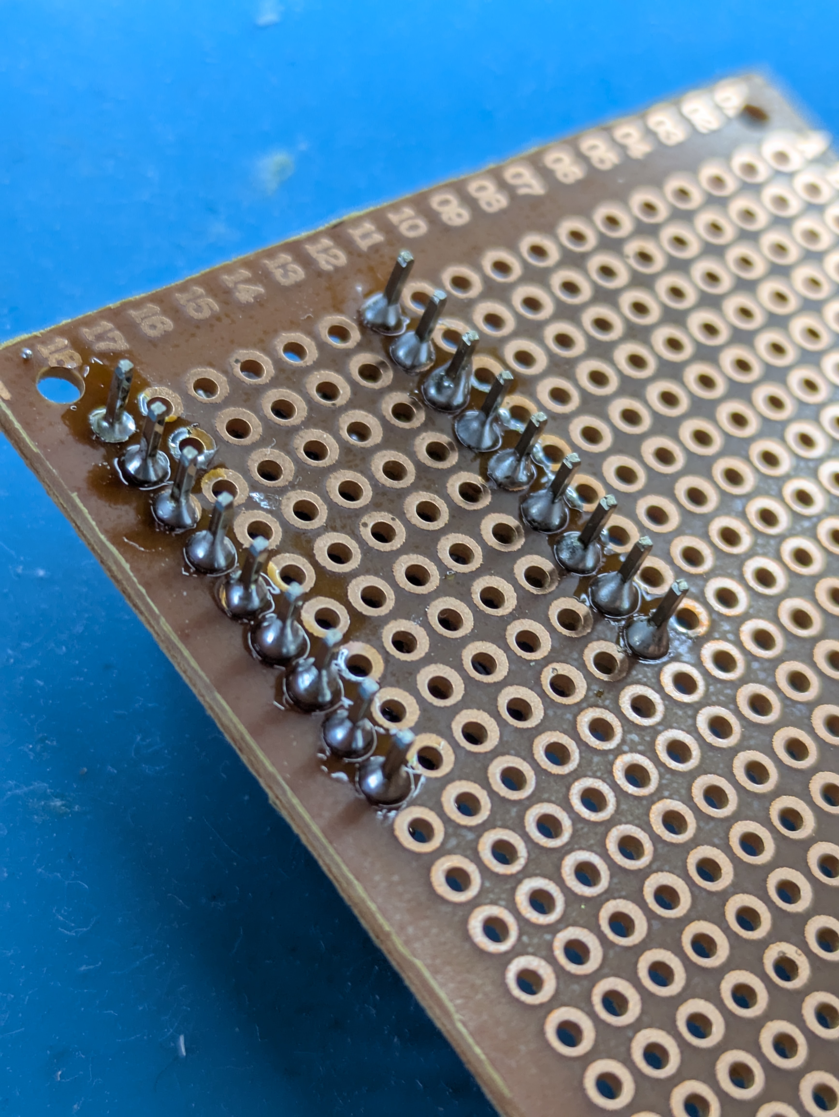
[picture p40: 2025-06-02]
HIDtaiko_connector_rp2040/images/rp2040build guide/5.jpg

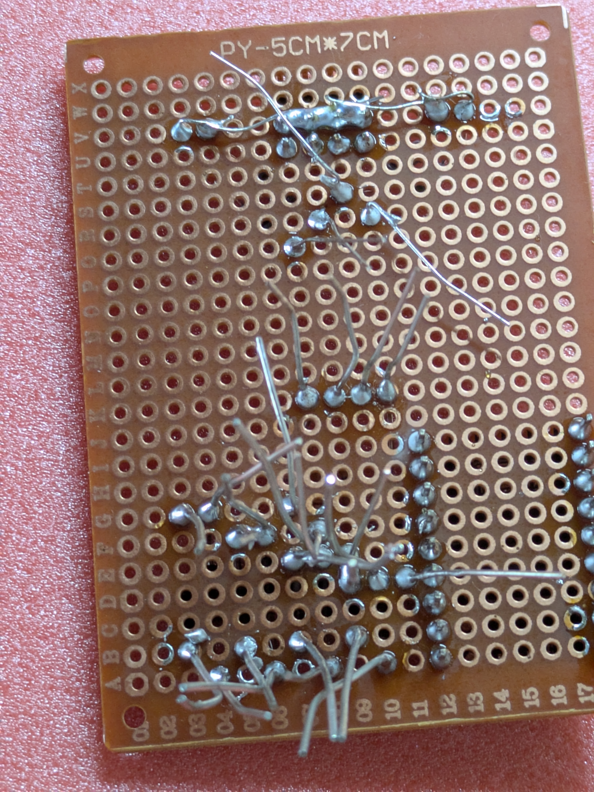
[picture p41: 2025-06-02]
HIDtaiko_connector_rp2040/images/rp2040build guide/10.jpg

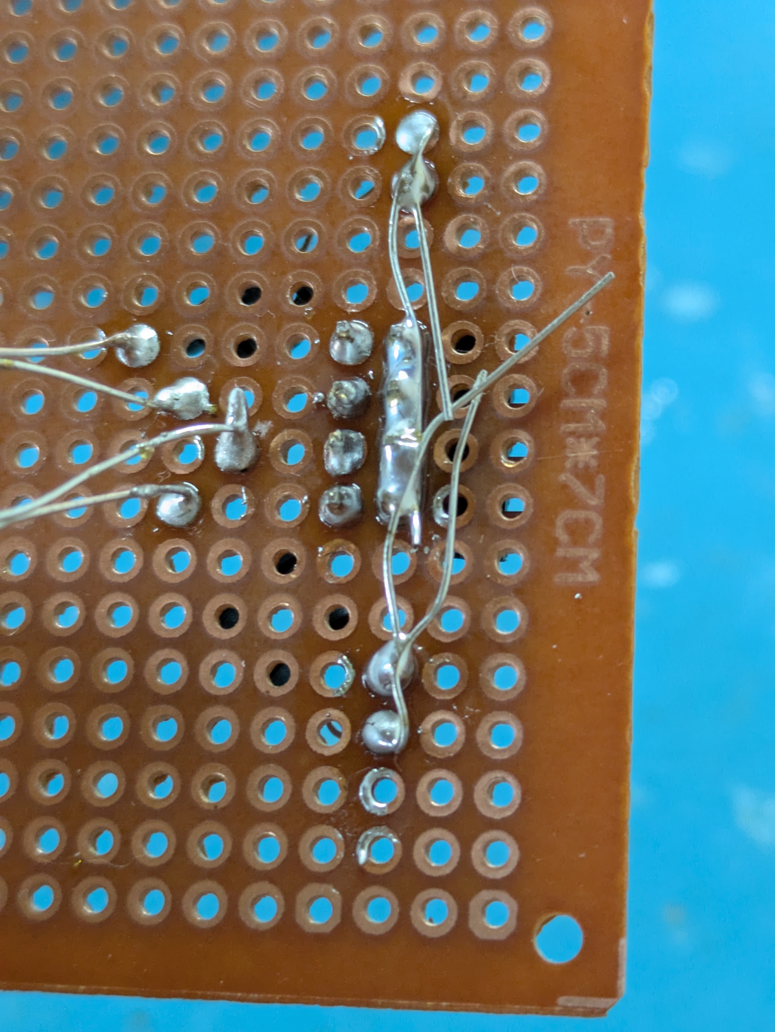
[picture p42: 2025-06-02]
HIDtaiko_connector_rp2040/images/rp2040build guide/9.jpg

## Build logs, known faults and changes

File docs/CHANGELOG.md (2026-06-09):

# docs Changelog

## 2026-06-06

### 初期統合
- `ver1.3_webapp_rp2040version/docs/` を HIDtaiko リポジトリの `docs/` として統合
- GitHub Pages 配信元として使用予定

### バージョンナビ追加
- ヘッダー左上に V1.1 / V1.2 切り替えリンクを追加（`main.css` に `.version-nav` スタイル追加）
- 元の「RP2040」表記を「V1.1」に修正

### V1.2 ページ追加（`v12.html` / `v12.js`）
- `index.html` をベースに V1.2 用ページを新規作成
- 主な差分：
  - ボーレート 115200 → 9600（`v12.js`）
  - 感度スライダー max: 500、デフォルト: 右縁=80 / 右面=130 / 左面=130 / 左縁=80
  - Delay スライダー max: Adelay=25 / Bdelay=40 / Cdelay=40 / Ddelay=40 / Hdelay=40
  - Delay デフォルト: 8 / 6 / 13 / 10 / 0 ms
  - 接続時ステータス表示「V1.2接続済み」
  - ファームウェア更新手順を Arduino IDE 方式に変更

### EN/JP 切り替え追加（`i18n.js`）
- ヘッダーに EN/JP トグルボタンを追加
- `body.is-en` / `body.is-ja` クラスで `.i18n-ja` / `.i18n-en` 要素を CSS で切り替え
- `localStorage` に言語設定を保存（キー: `hidtaiko-lang`）、ページ跨ぎで引き継ぎ
- 翻訳対象：ボタン、カードタイトル、パッドラベル、説明文全文、ファームウェア手順

### 感度調整ガイド改訂（両ページ共通）
- 手順を2ステップに整理：
  1. 確実な反応を保ちながら感度を下げる（値を大きく）
  2. Ddelay → Bdelay → Adelay → Cdelay の順で各 Delay を最小化
- 感度と Delay のトレードオフを補足として追記
- 日英両対応

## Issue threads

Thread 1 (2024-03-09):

SwitchControlLibrary.h

SZ01MW, 2024-03-09:
こんにちは、私はあなたのおかげでドラムを作っています。感謝しています。今、コードをアップロードしようとしています（コードをコピーする前にNintendoSwitchControlLibraryをすでにインストールしています）。コードを「プロ　マイクロ」にアップロードするときに、次のエラーが発生します。

sketch_mar08a:23:10: fatal error: SwitchControlLibrary.h: No such file or directory
compilation terminated.
exit status 1
SwitchControlLibrary.h: No such file or directory

プログラミングの初心者なので、解決方法がまったくわかりません。

kasasiki3, 2024-03-09:
このエラーは、Arduinoのコンパイル時に「SwitchControlLibrary.h」ファイルが見つからないために発生しています。以下のいくつかの可能性が考えられますので、確認してみてください。

ライブラリの追加作業が失敗している: エラー内容から、「SwitchControlLibrary.h」ファイルが見つからないことがわかります。ライブラリの追加手順を再確認してください。必要なライブラリが正しくインストールされていることを確認してください。
ファイルの場所が正しくない: 「No such file or directory」とあるので、「SwitchControlLibrary.h」フォルダの場所が正しくない可能性があります。ファイルが存在するディレクトリを再度確認してください。
ファイル名のスペルミス: ファイル名が正確に入力されているか確認してください。スペルミスがある場合、ファイルが見つからないエラーが発生します。
[これらのポイントをチェックして、問題を解決してみてください。](https://qiita.com/yasumae0819/questions/652bf291d414f23a7ab5)

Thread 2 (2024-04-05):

sketch_developmentSWをコンパイルするときにエラーが発生する

kasasiki3, 2024-04-05:
https://github.com/mike-matera/ArduinoSTL/issues/56

こちらのような症状が出る場合はAVR ボードのバージョンを1.8.2にしてください。

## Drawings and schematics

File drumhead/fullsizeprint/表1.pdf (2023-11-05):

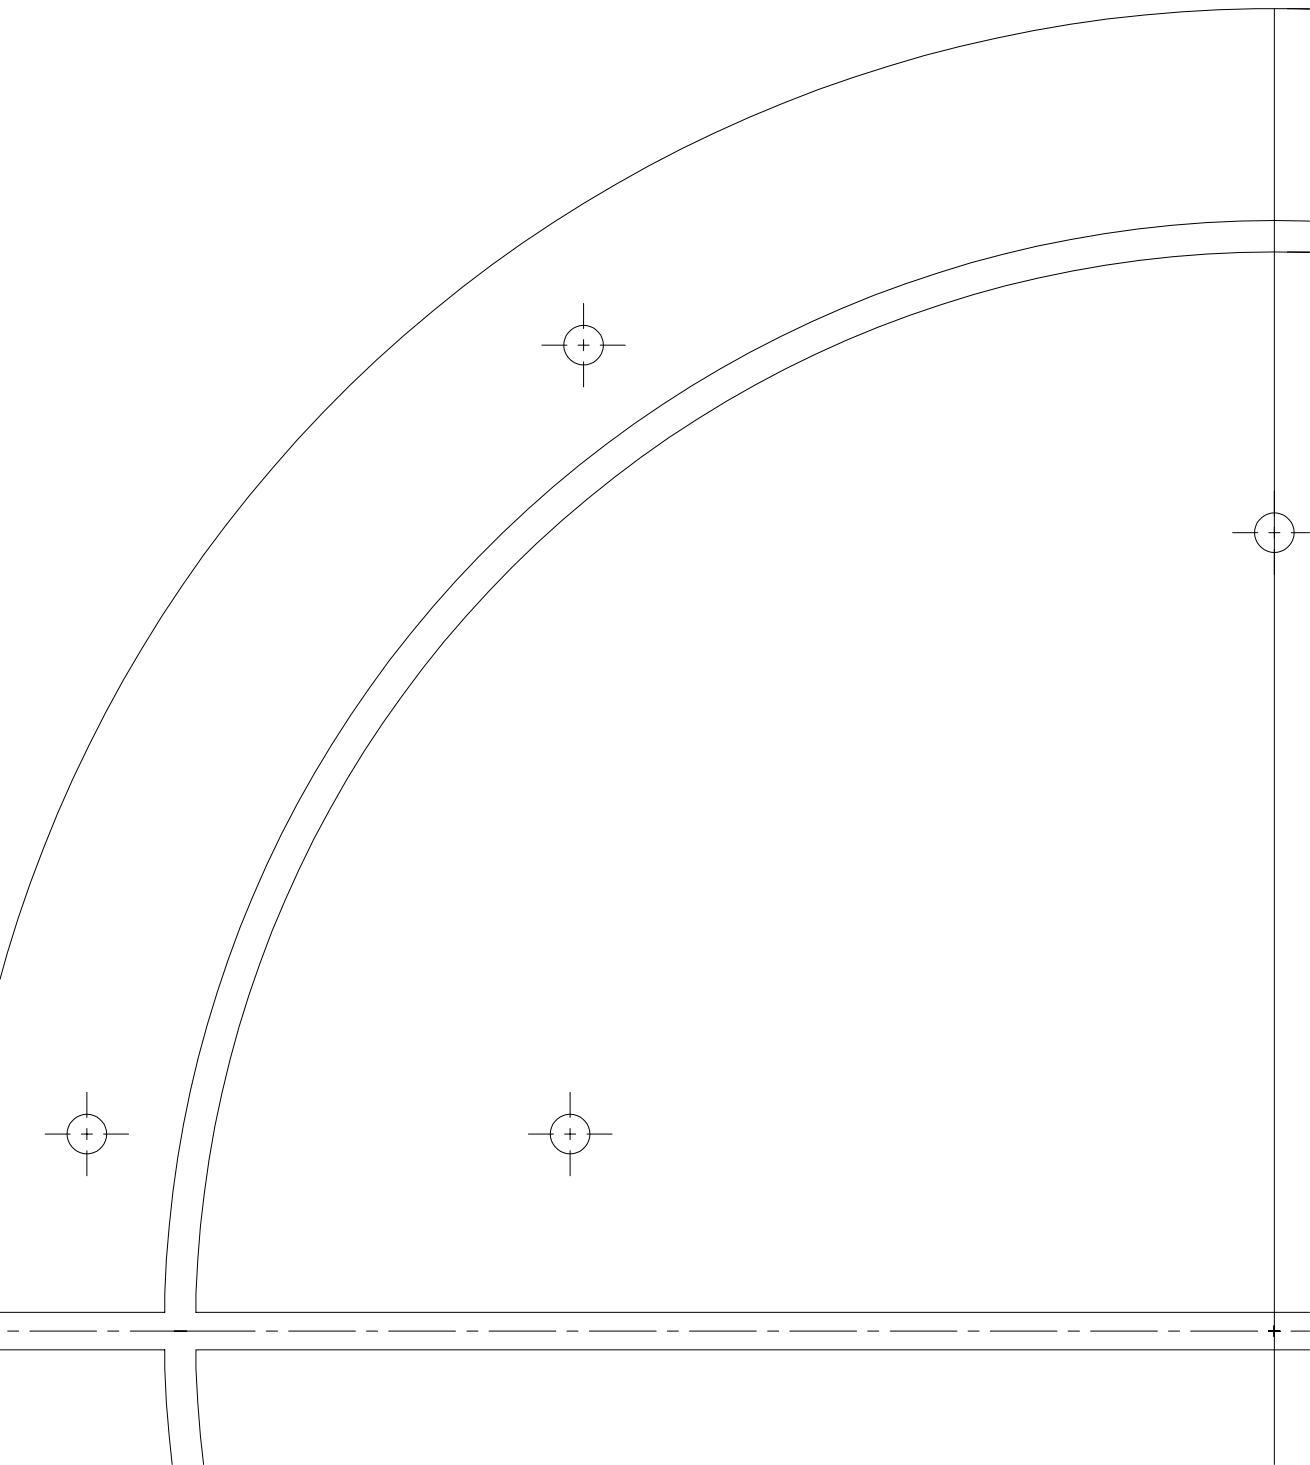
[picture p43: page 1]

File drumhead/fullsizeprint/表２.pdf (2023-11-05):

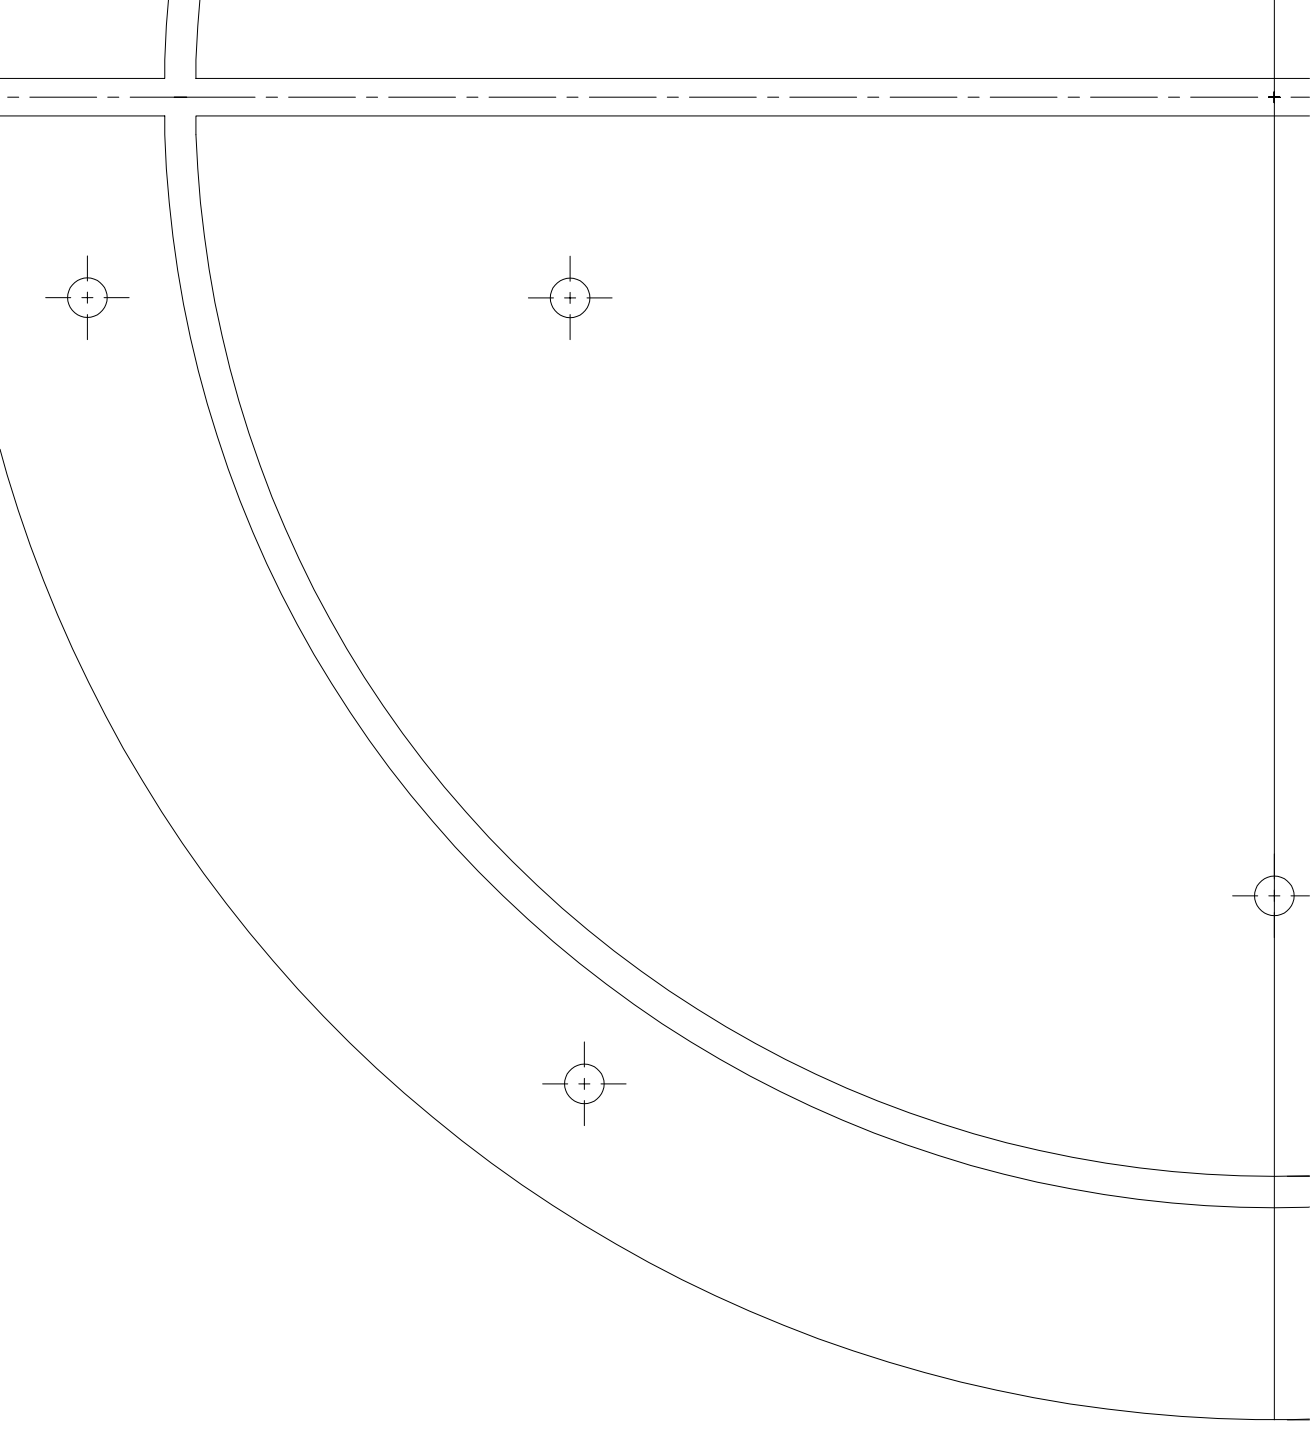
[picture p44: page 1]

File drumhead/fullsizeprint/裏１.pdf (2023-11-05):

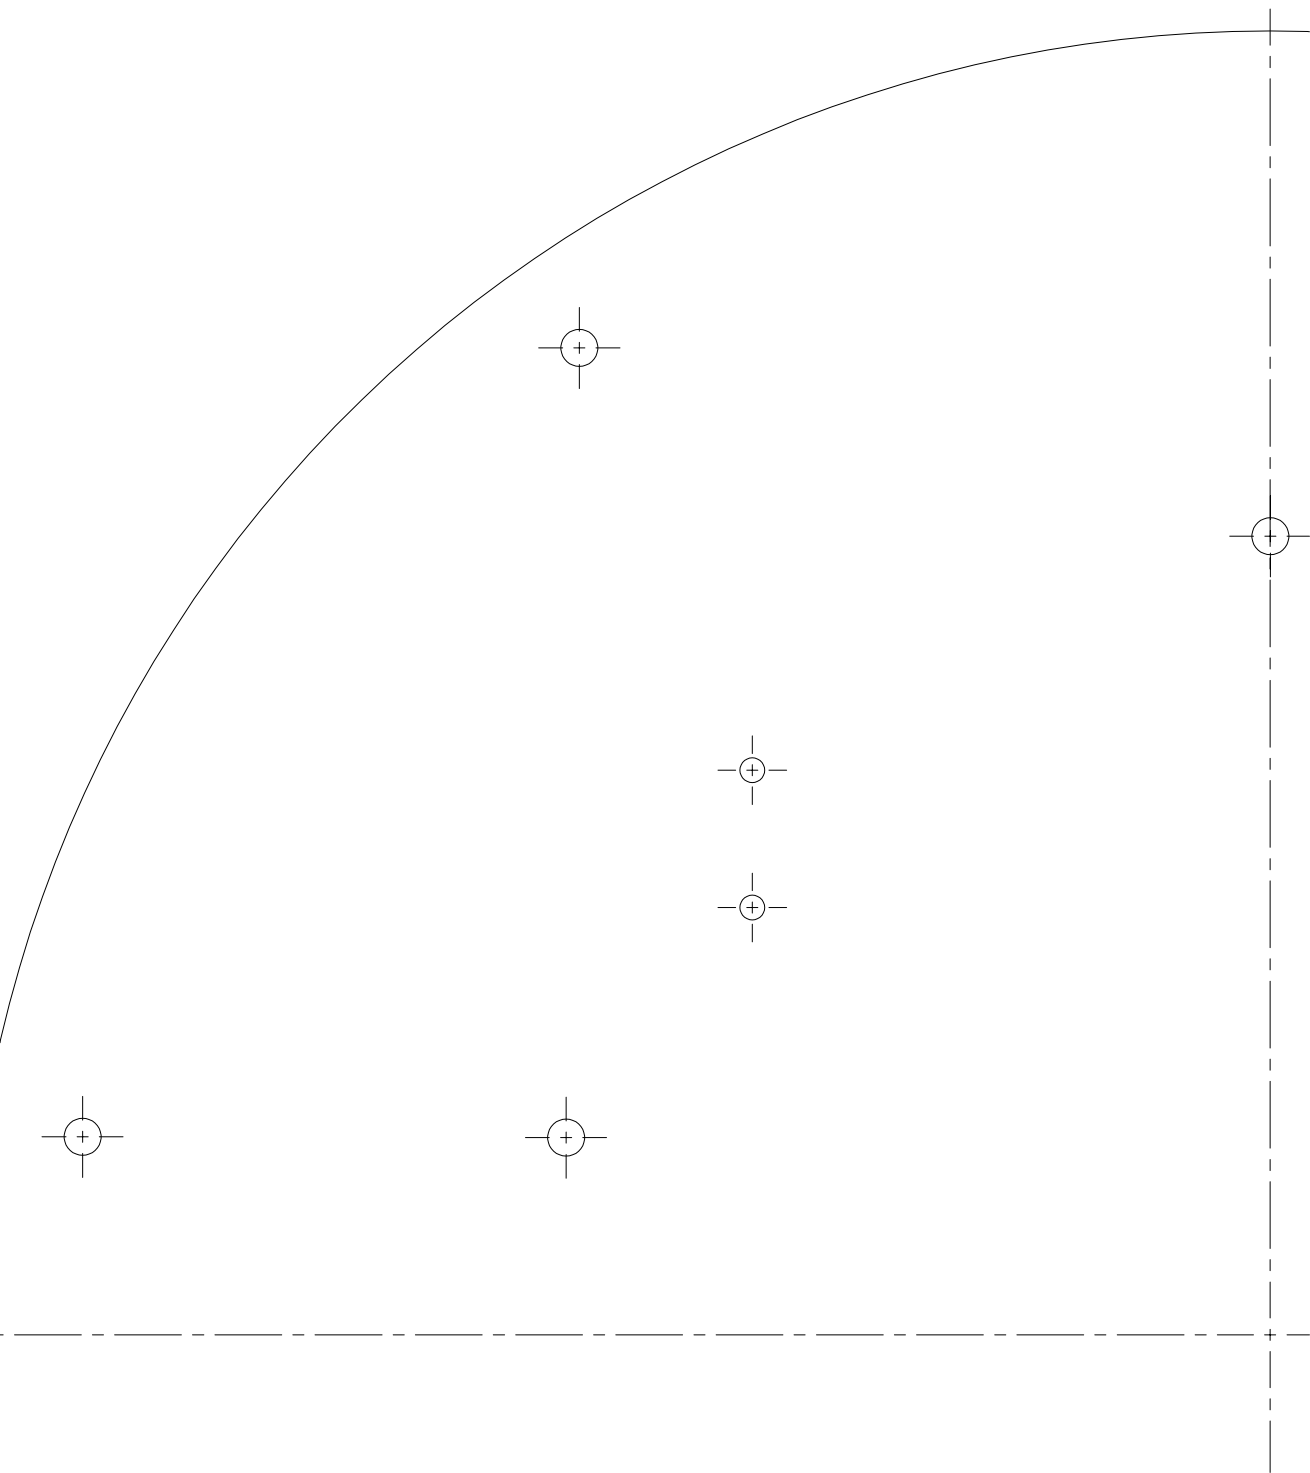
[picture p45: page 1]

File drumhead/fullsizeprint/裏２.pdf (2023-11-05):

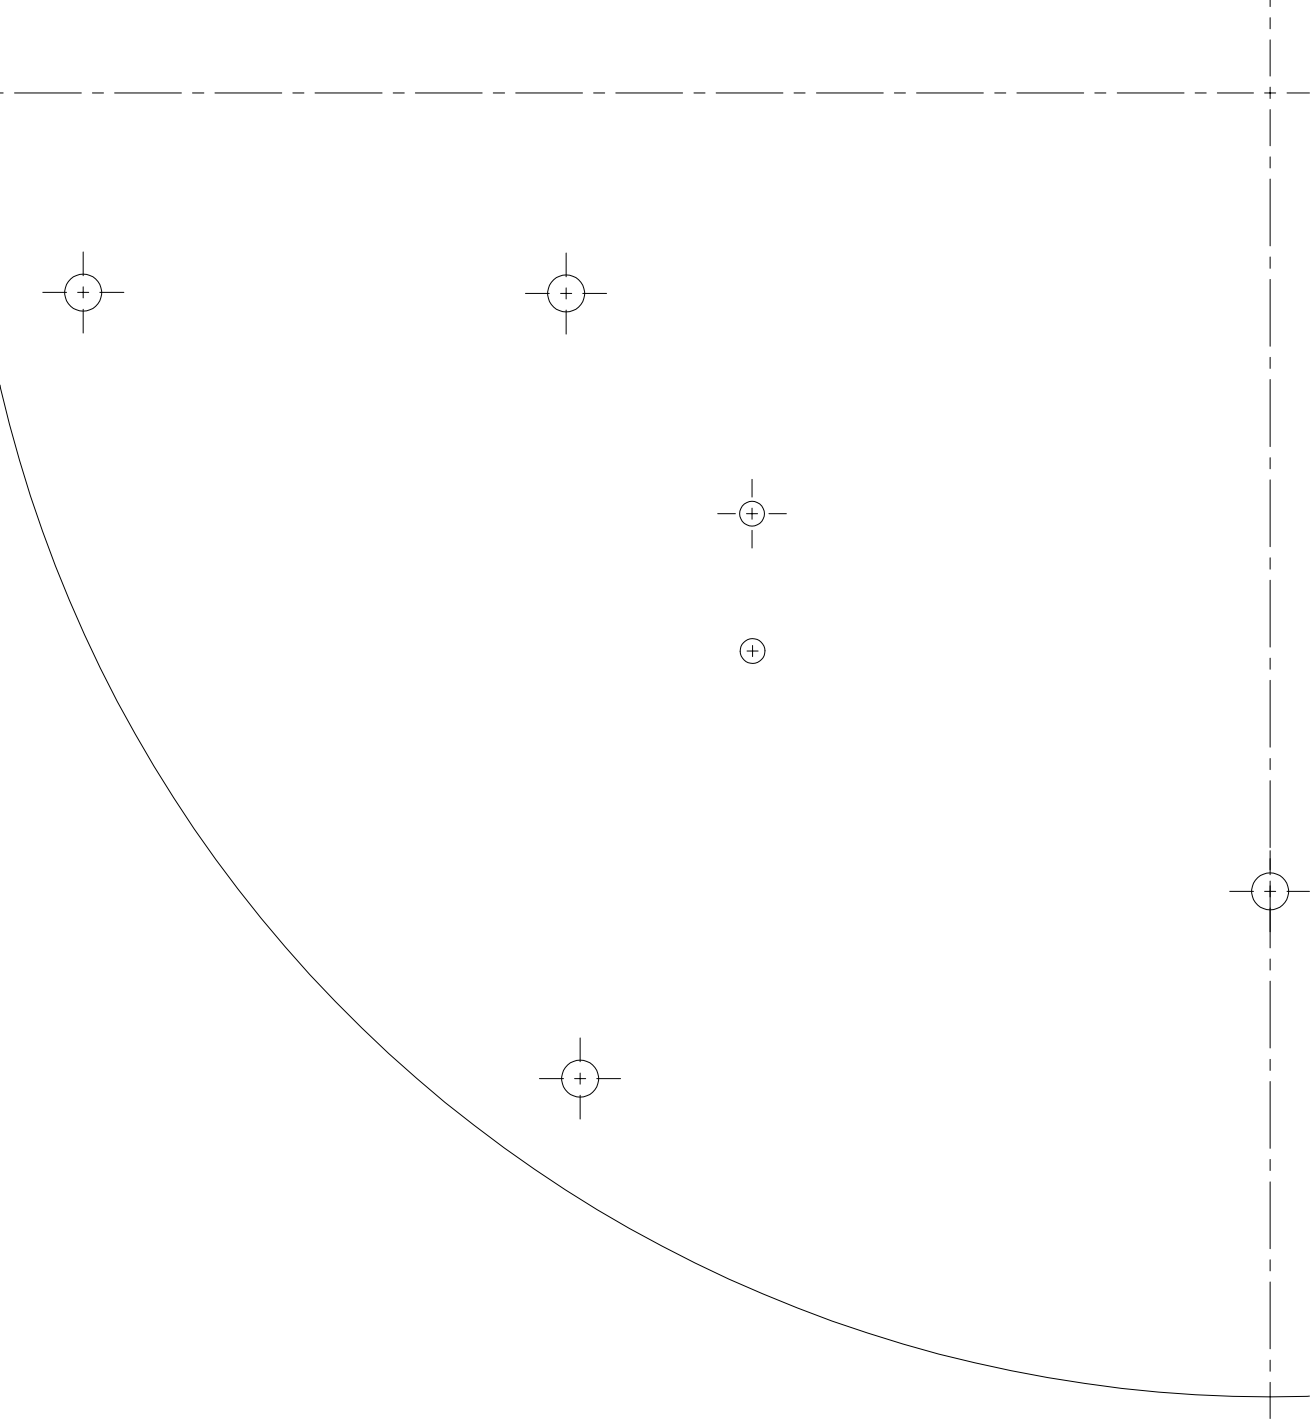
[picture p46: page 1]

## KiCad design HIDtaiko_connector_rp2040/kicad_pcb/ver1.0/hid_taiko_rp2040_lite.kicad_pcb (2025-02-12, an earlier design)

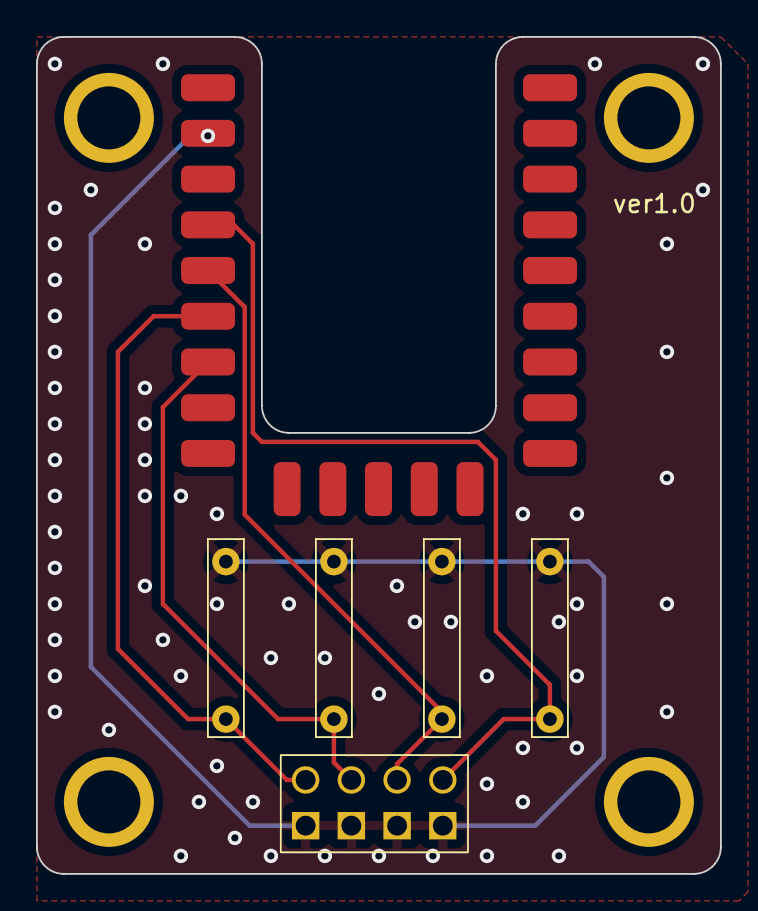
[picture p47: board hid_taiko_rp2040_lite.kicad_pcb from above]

Board: 2 copper layers, 38.0 x 46.5 mm, 10 parts (0 on the bottom side), 5 nets.

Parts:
J2, J2#2, J2#3, J2#4: Conn_02x05; m3 nezi
U2: PinHeader_2x4_P2.54mm_Vertical_Staggered
U3: rp2040_micro_board
U5, U6, U7, U8: スルーホールの一般的な 抵抗

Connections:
unnamed: U2.5 (1_b), U3.27 (ADC1), U8.1
unnamed: U2.6 (2_b), U3.26 (ADC0), U7.1
unnamed: U2.7 (3_b), U3.28 (ADC2), U6.1
unnamed: U2.8 (4_b), U3.29 (ADC3), U5.1
unnamed: U2.1, U2.2, U2.3, U2.4, U3.31 (GND), U5.2, U6.2, U7.2, U8.2

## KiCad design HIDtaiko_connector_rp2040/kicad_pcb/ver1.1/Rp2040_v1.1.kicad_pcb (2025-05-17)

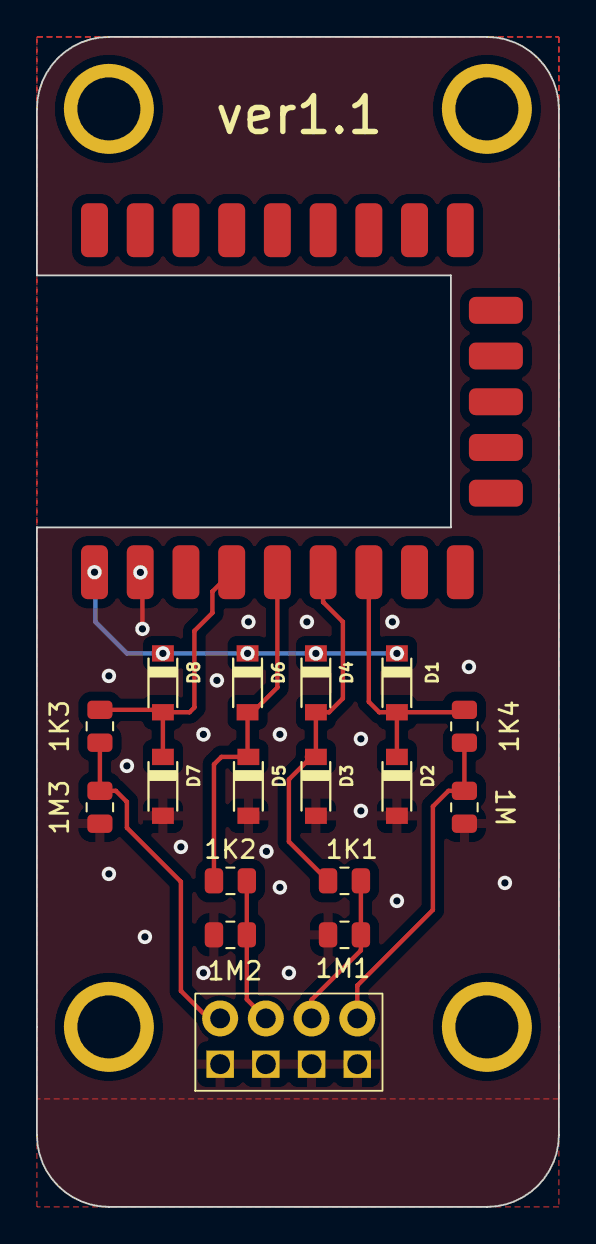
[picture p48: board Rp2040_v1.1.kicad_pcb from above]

Board: 2 copper layers, 29.0 x 65.0 mm, 22 parts (0 on the bottom side), 10 nets.

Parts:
1K1, 1K2, 1K3, 1K4, 1M1, 1M2, 1M3, 1M4: R; R_0805_2012Metric
D1, D2, D3, D4, D5, D6, D7, D8: MBR0520LT1G; SOD3716X135N
J2, J2#2, J2#3, J2#4: M3; m3 nezi
U1: rp2040_micro_board
U2: PinHeader_2x4_P2.54mm

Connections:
+5V: D1.C, D4.C, D6.C, D8.C, U1.32 (5V)
GND: 1M1.2, 1M2.2, 1M3.2, 1M4.2, D2.A, D3.A, D5.A, D7.A, U1.31 (GND), U2.1, U2.2, U2.3, U2.4
unnamed: 1K4.1, D1.A, D2.C, U1.26 (ADC0)
unnamed: 1K1.1, D3.C, D4.A, U1.27 (ADC1)
unnamed: 1K2.1, D5.C, D6.A, U1.28 (ADC2)
unnamed: 1K3.1, D7.C, D8.A, U1.29 (ADC3)
unnamed: 1K3.2, 1M3.1, U2.5 (1_b)
unnamed: 1K2.2, 1M2.1, U2.6 (2_b)
unnamed: 1K1.2, 1M1.1, U2.7 (3_b)
unnamed: 1K4.2, 1M4.1, U2.8 (4_b)

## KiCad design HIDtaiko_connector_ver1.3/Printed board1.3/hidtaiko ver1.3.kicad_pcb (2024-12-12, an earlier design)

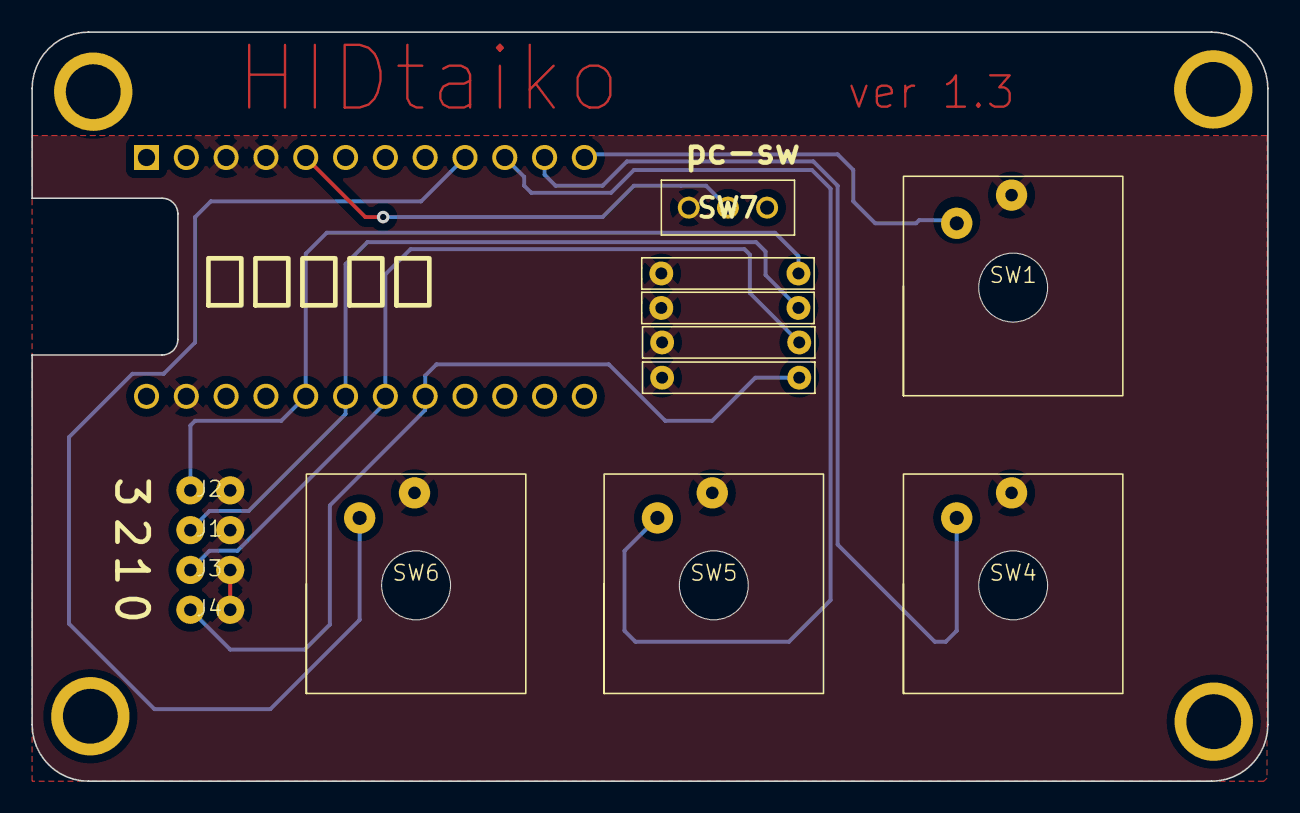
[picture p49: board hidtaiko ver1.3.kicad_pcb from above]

Board: 2 copper layers, 78.9 x 47.8 mm, 17 parts (1 on the bottom side), 10 nets.

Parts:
J1, J2#3, J3, J4: Conn_01x02_Pin; 2pinHedar
J2, J2#2, J2#4: Conn_02x05; m3 nezi
R1, R2, R3, R4: R; スルーホールの一般的な 抵抗
SW1, SW4, SW5, SW6: SW_PUSH; Redragon smd rgb mx
SW7: swpc; SS12D00G3
U1: ProMicro; ProMicro-NoSilk

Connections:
unnamed: J1.1, R1.1, U1.19 (A2/F5)
unnamed: J1.2, J2#3.2, J3.2, J4.2, R1.2, R2.2, R3.2, R4.2, SW1.2, SW4.2, SW5.2, SW6.2, SW7.1, U1.3 (GND), U1.4 (GND), U1.23 (GND)
unnamed: J2#3.1, R2.1, U1.20 (A3/F4)
unnamed: J3.1, R3.1, U1.18 (A1/F6)
unnamed: J4.1, R4.1, U1.17 (A0/F7)
unnamed: SW4.1, U1.11 (B4/8)
unnamed: SW1.1, U1.12 (B5/9)
unnamed: SW6.1, U1.9 (D7/6)
unnamed: SW5.1, U1.10 (E6/7)
unnamed: SW7.2, U1.5 (SDA/D1/2)

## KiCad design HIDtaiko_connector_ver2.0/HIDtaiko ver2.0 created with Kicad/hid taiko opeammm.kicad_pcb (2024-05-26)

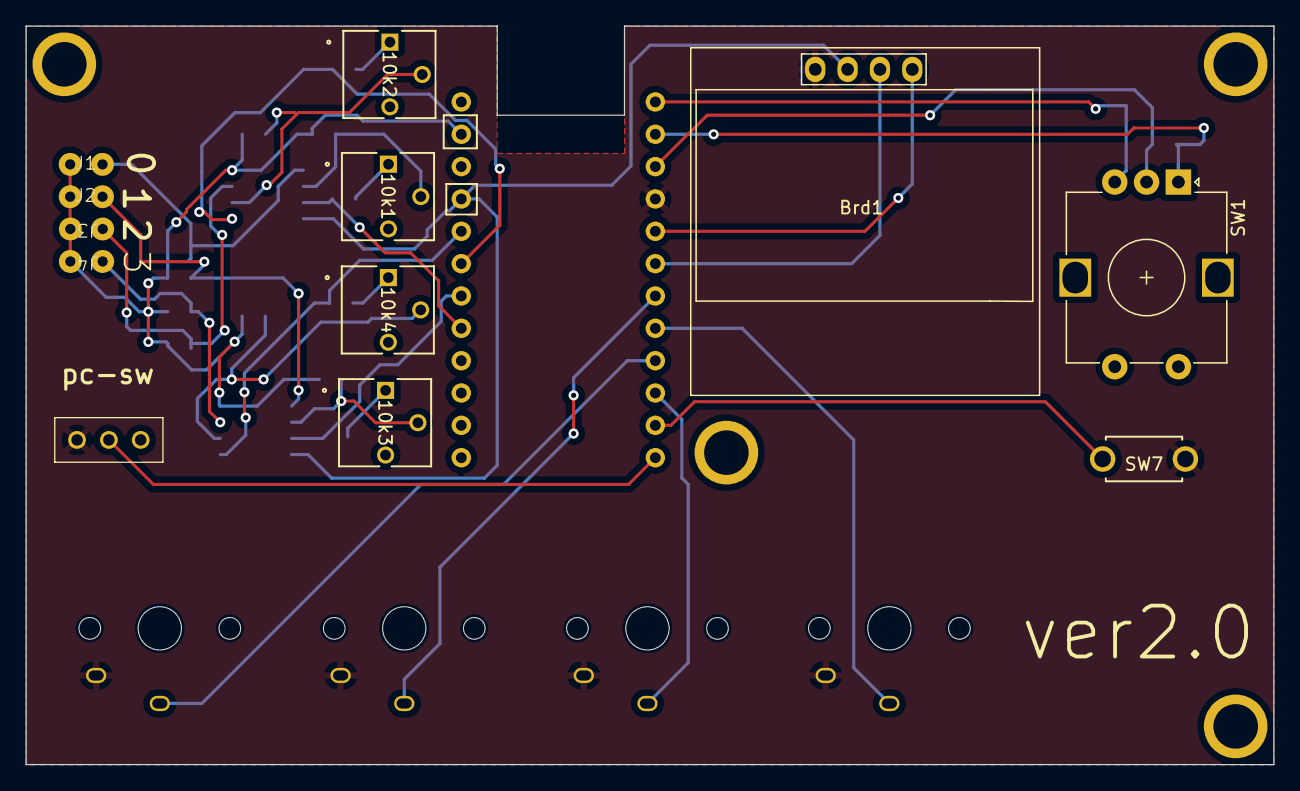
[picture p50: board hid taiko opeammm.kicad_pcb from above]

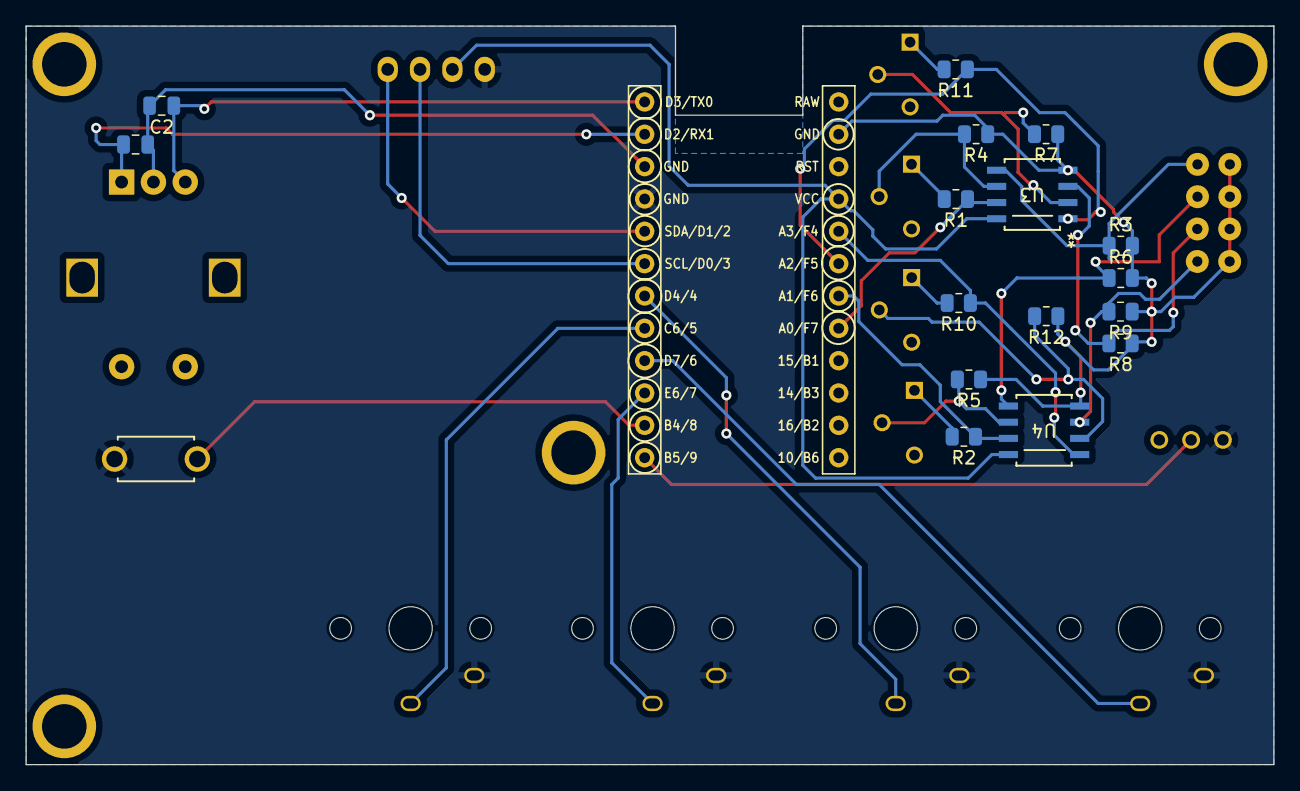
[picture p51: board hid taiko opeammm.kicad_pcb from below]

Board: 2 copper layers, 98.0 x 58.0 mm, 34 parts (17 on the bottom side), 30 nets.

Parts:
10k1, 10k2, 10k3, 10k4: Varistor; 3362P
Brd1: SSD1306; 128x64OLED2
C1, C2: C; C_0805_2012Metric
J1, J2, J3, J4: Conn_01x02_Pin; 2pin
J2#2: Conn_02x05; m3 nezi
R1, R2, R4, R5, R7, R10, R11, R12: 10k; R_0805_2012Metric
R3, R6, R8, R9: R; R_0805_2012Metric
SW1: RotaryEncoder; RotaryEncoder_Alps_EC12E-Switch_Vertical_H20mm
SW2: SW_SPDT_321; SS12D00G3
SW3, SW4, SW5, SW6: SW_Push; Kailh_Choc_V1
SW7: SW_Push; SW_PUSH_6x3mm
U1: ProMicro
U3, U4: NJM4580E-ND; NJR-SOP8_NJR

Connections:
unnamed: 10k1.1, R1.2
unnamed: 10k2.1, R11.2
unnamed: 10k3.1, R2.2
unnamed: 10k4.1, R10.2
unnamed: Brd1.1 (GND), SW2.3 (A), SW3.1, SW4.1, SW5.1, SW6.1, SW7.1, U1.4 (GND)
unnamed: Brd1.3 (SCL), U1.6 (SCL/D0/3)
unnamed: Brd1.4 (SDA), U1.5 (SDA/D1/2)
unnamed: Brd1.2 (VCC), U1.21 (VCC), U3.8 (V+), U4.8 (V+)
unnamed: C1.1, C2.2, SW1.C, U1.3 (GND)
unnamed: J1.1, J2.1, J3.2, J4.2, R3.2, R4.1, R5.1, R6.2, R7.1, R8.1, R9.1, R12.1, U1.23 (GND), U3.4 (V-), U4.4 (V-)
unnamed: J1.2, R3.1, U3.5 (BINPUT+)
unnamed: J2.2, R6.1, U4.5 (BINPUT+)
unnamed: J3.1, R8.2, U3.3 (AINPUT+)
unnamed: J4.1, R9.2, U4.3 (AINPUT+)
unnamed: SW2.2 (B), U1.12 (B5/9)
unnamed: R1.1, U1.17 (A0/F7), U3.7 (BOUTPUT)
unnamed: R2.1, U1.18 (A1/F6), U4.7 (BOUTPUT)
unnamed: R11.1, U1.19 (A2/F5), U3.1 (AOUTPUT)
unnamed: R10.1, U1.20 (A3/F4), U4.1 (AOUTPUT)
unnamed: SW7.2, U1.11 (B4/8)
unnamed: SW4.2, U1.8 (C6/5)
unnamed: C1.2, SW1.A, U1.2 (D2/RX1)
unnamed: C2.1, SW1.B, U1.1 (D3/TX0)
unnamed: SW5.2, U1.7 (D4/4)
unnamed: SW3.2, U1.9 (D7/6)
unnamed: SW6.2, U1.10 (E6/7)
unnamed: 10k2.2, R7.2, U3.2 (AINPUT-)
unnamed: 10k1.2, R4.2, U3.6 (BINPUT-)
unnamed: 10k4.2, R12.2, U4.2 (AINPUT-)
unnamed: 10k3.2, R5.2, U4.6 (BINPUT-)

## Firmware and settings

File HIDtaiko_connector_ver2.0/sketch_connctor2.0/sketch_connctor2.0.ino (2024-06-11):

#include <Keyboard.h>
#include <SwitchControlLibrary.h>
#include <Wire.h>
#include <Adafruit_GFX.h>
#include <Adafruit_SSD1306.h>
#include <EEPROM.h>
void pulse_counter(); // 関数の前方宣言
void clearArea(int16_t x, int16_t y, int16_t w, int16_t h); // 関数の前
const int A_pin = 0; // エンコーダーのpin
const int B_pin = 1;
int count = 0;
int lastcount = 0;




char key0 = 6;//左から順に
char key1 = 4;
char key2 = 7;
char key3 = 5;
char swpc = 9;
int keyl = 8;//レイヤー用
char ct = 10;//ディスプレイ操作のdelay
char ctt= 20;

int valuec = 0; 
bool delayc = false;
bool delayall = false;
bool delayallc = false;
bool layer = false;  // 現在のフラグ状態  keyL
bool lastkeyl = HIGH;  // 前回のスイッチの状態
bool key0f = false;  // 前回のスイッチの状態 key0
bool lastkey0 = HIGH;  // 前回のスイッチの状態
bool key1f = false;  // 前回のスイッチの状態 key1
bool lastkey1 = HIGH;  // 前回のスイッチの状態
bool key2f = false;  // 前回のスイッチの状態 key2
bool lastkey2 = HIGH;  // 前回のスイッチの状態
bool key3f = false;  // 前回のスイッチの状態 key3
bool lastkey3 = HIGH;  // 前回のスイッチの状態
Adafruit_SSD1306 display(-1);
int se0 = 0;
int se1 = 0;
int se2 = 0;
int se3 = 0;
int A1pin = A1;
int A2pin = A2;
int A0pin = A0;
int A3pin = A3;
char left = 'd';        //左カッ
char middleleft = 'f';  //左ドン
char middletight = 'j'; //右ドン
char right = 'k';       //右カッ
//SW(調節はお勧めしません)
char aa = 17; //入力のdelay
char cc = 20;
char swA = 1;
char swB = 3;
/*(PC)Aはどれかのキーが入力されてから、そのキーの次の入力を受け付けない時dk間です。
(PC)Bはどれかのキーが入力されてから、4キーすべての入力を受け付けない時間です。
*/
char A = 1; //キー単体のdelay
char B = 12; //キー全体のdelay
char C = 32;
char p1 = 35;//かっが入力された後のドンのディレイ


char de = 20;
long int sv1 =  0;
long int sv2 =  0;
long int sv3 =  0;
long int sv0 =  0;
long int ti1 =  0;
long int ti2 =  0;
long int ti3 =  0;
long int ti0 =  0;
long int time =  0;
long int ti = 0;
bool swswitching = false;
void setup() {
  pinMode(A_pin, INPUT_PULLUP);//ロータリーエンコーダの設定
  pinMode(B_pin, INPUT_PULLUP);
  attachInterrupt(digitalPinToInterrupt(A_pin), pulse_counter, CHANGE);


  Keyboard.begin();
  display.begin(SSD1306_SWITCHCAPVCC, 0x3C);
  display.clearDisplay();
  display.display();
  pinMode(swpc, INPUT_PULLUP);
  pinMode(keyl, INPUT_PULLUP);
  pinMode(key0, INPUT_PULLUP);
  pinMode(key1, INPUT_PULLUP);
  pinMode(key2, INPUT_PULLUP);
  pinMode(key3, INPUT_PULLUP);
 Serial.begin(9600);
 se0 = EEPROM.read(0);
    se1 = EEPROM.read(1);
      se2 = EEPROM.read(2);
        se3 = EEPROM.read(3);
        B = EEPROM.read(4);
        C = EEPROM.read(5);
        p1 = EEPROM.read(6);
  if (digitalRead(9) == LOW) {
  swswitching = true;
  delay(100);
  }
  if(swswitching == false){
  SwitchControlLibrary().sendReport();
  delay(400);
  SwitchControlLibrary().releaseButton(Button::LCLICK);
  SwitchControlLibrary().sendReport();
  delay(400);
    SwitchControlLibrary().pressButton(Button::LCLICK);
  SwitchControlLibrary().sendReport();
  delay(400);
  SwitchControlLibrary().releaseButton(Button::LCLICK);
  SwitchControlLibrary().sendReport();
  delay(400);
    SwitchControlLibrary().pressButton(Button::LCLICK);
  SwitchControlLibrary().sendReport();
  delay(400);
  SwitchControlLibrary().releaseButton(Button::LCLICK);
  SwitchControlLibrary().sendReport();
  delay(400);
  }
}












void loop() {
 if(swswitching == true){
  long int a3 = analogRead(A3pin);
  long int a0 = analogRead(A0pin);
  long int a1 = analogRead(A1pin);
  long int a2 = analogRead(A2pin);
  time = millis();
    if (a3 - sv3 >= se3 && time - ti3 > A && time- ti > C) {
  Keyboard.write(right);
  ti3 = millis();
  ti = millis();
  }
    if (a0 - sv0 >= se0 && time - ti0 > A && time- ti > C) {
  Keyboard.write(left);
  ti0 = millis();
  ti = millis();
  }
 if (a1 - sv1 >= se1 && time - ti1 > A && time- ti > B && time - ti0 > p1 && time - ti3 > p1) {
  Keyboard.write(middleleft);
  ti1 = millis();
  ti = millis();
  }
    if (a2 - sv2 >= se2 && time - ti2 > A && time- ti > B && time - ti0 > p1 && time - ti3 > p1) {
  Keyboard.write(middletight);
  ti2 = millis();
  ti = millis();
  }
  sv3 = a3;
  sv0 = a0;
  sv1 = a1;
  sv2 = a2;
  /*
      if (digitalRead(key0) == LOW && lastkey0 == HIGH && layer == false) {//下中
  Keyboard.write(KEY_ESC); 
 delay(de);
  }
      if (digitalRead(key1) == LOW && lastkey1 == HIGH && layer == false) {//下左　 KEY_ESC) KEY_DOWN_ARROW KEY_RETURN
  Keyboard.write(KEY_DOWN_ARROW); 
 delay(de);
  }
      if (digitalRead(key2) == LOW && lastkey2 == HIGH && layer == false) {
  Keyboard.write(KEY_UP_ARROW);  //上左
 delay(de);
  }
    if (digitalRead(key3) == LOW && lastkey3 == HIGH && layer == false) { //上右
  Keyboard.write(KEY_F1); 
 delay(de);
  }
  */
 }


   if(swswitching == false){
  long int a3 = analogRead(A3pin);
  long int a0 = analogRead(A0pin);
  long int a1 = analogRead(A1pin);
  long int a2 = analogRead(A2pin);
  time = millis();


  if (a3 - sv3 >= se3 && time - ti3 > swA && time- ti > swB) {
  SwitchControlLibrary().pressButton(Button::ZL);
  SwitchControlLibrary().sendReport();
  delay(cc);
  SwitchControlLibrary().releaseButton(Button::ZL);
  SwitchControlLibrary().sendReport();
  delay(aa);
  ti3 = millis();
  ti = millis();
  }
    if (a0 - sv0 >= se0 && time - ti0 > swA && time- ti > swB) {
  SwitchControlLibrary().pressButton(Button::ZR);
  SwitchControlLibrary().sendReport();
  delay(cc);
  SwitchControlLibrary().releaseButton(Button::ZR);
  SwitchControlLibrary().sendReport();
  delay(aa);
  ti0 = millis();
  ti = millis();
  }
    if (a1 - sv1 >= se1 && time - ti1 > swA && time- ti > swB) {
  SwitchControlLibrary().pressButton(Button::RCLICK);
  SwitchControlLibrary().sendReport();
  delay(cc);
  SwitchControlLibrary().releaseButton(Button::RCLICK);
  SwitchControlLibrary().sendReport();
  delay(aa);


  ti1 = millis();
  ti = millis();
  }
    if (a2 - sv2 >= se2 && time - ti2 > swA && time- ti > swB) {
  SwitchControlLibrary().pressButton(Button::LCLICK);
  SwitchControlLibrary().sendReport();
  delay(cc);
  SwitchControlLibrary().releaseButton(Button::LCLICK);
  SwitchControlLibrary().sendReport();
  delay(aa);
  ti2 = millis();
  ti = millis();
  }
  sv3 = a3;
  sv0 = a0;
  sv1 = a1;
  sv2 = a2;
    if (digitalRead(key0) == LOW) {//上左　 KEY_ESC) KEY_DOWN_ARROW KEY_RETURN
  SwitchControlLibrary().pressButton(Button::R);
  SwitchControlLibrary().sendReport();
  delay(de);
  SwitchControlLibrary().releaseButton(Button::R);
  SwitchControlLibrary().sendReport();
  delay(de);
  }
  if (digitalRead(key1) == LOW) {//上中　 KEY_ESC) KEY_DOWN_ARROW KEY_RETURN
  SwitchControlLibrary().pressButton(Button::PLUS);
  SwitchControlLibrary().sendReport();
  delay(de);
  SwitchControlLibrary().releaseButton(Button::PLUS);
  SwitchControlLibrary().sendReport();
  delay(de);
  }


  if (digitalRead(key2) == LOW) { //上右
  SwitchControlLibrary().pressButton(Button::A);
  SwitchControlLibrary().sendReport();
  delay(de);
  SwitchControlLibrary().releaseButton(Button::A);
  SwitchControlLibrary().sendReport();
  delay(de);
  }
  if (digitalRead(key3) == LOW) { //下右
  SwitchControlLibrary().pressButton(Button::B);
  SwitchControlLibrary().sendReport();
  delay(de);
  SwitchControlLibrary().releaseButton(Button::B);
  SwitchControlLibrary().sendReport();
  delay(de);
  }
  }


//カウント変数を用意して、その数に応じて数値を変更するパーツを切り替える
//チャタは許されない
//変数の範囲を0から６に



    if (digitalRead(keyl) == LOW && lastkeyl == HIGH && layer == false) {//レイヤーの切り替え
    layer = true;
    display.setTextSize(1);
    display.setTextColor(WHITE);
    display.setCursor(0, 0);
    //display.println("edit");
      display.println(F("edit mode"));
      display.display();
    }
        else if(digitalRead(keyl) == LOW && lastkeyl == HIGH && layer == true){
      //HIDtaiko ver.2.0と表示させたりしたいね
      layer = false;
    display.clearDisplay();
         display.display();
      EEPROM.write (0,se0);
      EEPROM.write (1,se1);
      EEPROM.write (2,se2);
      EEPROM.write (3,se3);
      EEPROM.write (3,se3);
      EEPROM.write (4,B);
      EEPROM.write (5,C);
      EEPROM.write (6,p1);
    }


 
//ここまでがレイヤーの切り替え


if(layer == true){

   if (digitalRead(keyl) == LOW &&lastkeyl == HIGH) {
        display.clearDisplay();
         display.display();
          EEPROM.write (0,se0);
          EEPROM.write (1,se1);
          EEPROM.write (2,se2);
          EEPROM.write (3,se3);
          EEPROM.write (4,B);
          EEPROM.write (5,C);
          EEPROM.write (6,p1);
          layer = false;
          Serial.println("nannde?");
   }
          if (digitalRead(key0) == LOW && lastkey0 == HIGH){
    valuec++;
   // Serial.println("dasd");
    delay(5);
  }
  if (digitalRead(key1) == LOW && lastkey1 == HIGH){
    valuec--;
  //  Serial.println("dasd");
        delay(5);
  }
  if(valuec > 6){ //変数の値を0～６に制限する。
  valuec = 6;
}
else if(valuec < 0){
 valuec = 0;
}
Serial.println(valuec);

      if (valuec == 0 && key0f == false) {
      delay(ctt);
          delayall = false;
    delayallc = false;
    delayc = false;
    key0f = true;
    key1f = false;
    key2f = false;
    key3f = false;
count = se0;
      clearArea2(5,10,30,40);
    display.setTextSize(2);
    display.setTextColor(WHITE);
    display.setCursor(5 ,10);
    display.println("0");
      display.display();
  //    delay(ct);
      }
          if (valuec == 1 && key1f == false) {
          delay(ctt);
              delayall = false;
    delayallc = false;
    delayc = false;
    key1f = true;
    key0f = false;
    key2f = false;
    key3f = false;
      count = se1;
    clearArea2(5,10,30,40);
    display.setTextSize(2);
    display.setTextColor(WHITE);
    display.setCursor(5 ,10);
    display.println("1");
      display.display();
   //   delay(ct);
          }
          if (valuec == 2 && key2f == false) {
          delay(ctt);
              delayall = false;
    delayallc = false;
    delayc = false;
    key2f = true;
    key1f = false;
    key0f = false;
    key3f = false;
count = se2;
    clearArea2(5,10,30,40);
    display.setTextSize(2);
    display.setTextColor(WHITE);
    display.setCursor(5 ,10);
    display.println("2");
      display.display();
   //   delay(ct);
          }
          if (valuec == 3 && key3f == false) {
          delay(ctt);
    delayall = false;
    delayallc = false;
    delayc = false;
    key3f = true;
    key1f = false;
    key2f = false;
    key0f = false;
      count = se3;
    clearArea2(5,10,30,40);
    display.setTextSize(2);
    display.setTextColor(WHITE);
    display.setCursor(5 ,10);
    display.println("3");
      display.display();
 // delay(ct);
  }
  //こっからdelay系になる
  if(valuec == 4 && delayall == false){//Bのdelay
    delayall = true;
    delayallc = false;
    delayc = false;
    key1f = false;
    key2f = false;
    key0f = false;
    key3f = false;
    count = B;//全体delayの数値
    clearArea2(5,10,30,40);
    display.setTextSize(2);
    display.setTextColor(WHITE);
    display.setCursor(5 ,10);
    display.println("4");
    display.display();
 // delay(ct);
  }
    if(valuec == 5 && delayallc == false){//Bのdelay
    delayall = false;
    delayallc = true;
    delayc = false;
    key1f = false;
    key2f = false;
    key0f = false;
    key3f = false;
    count = C;//全体delayの数値
    clearArea2(5,10,30,40);
    display.setTextSize(2);
    display.setTextColor(WHITE);
    display.setCursor(5 ,10);
    display.println("5");
    display.display();
  //delay(ct);
  }
      if(valuec == 6 && delayc == false){//p1のdelay
    delayall = false;
    delayallc = false;
    delayc = true;
    key1f = false;
    key2f = false;
    key0f = false;
    key3f = false;
    count = p1;//
    clearArea2(5,10,30,40);
    display.setTextSize(2);
    display.setTextColor(WHITE);
    display.setCursor(5 ,10);
    display.println("6");
    display.display();
  //delay(ct);
  }
   
   
   
   
 
 
  if(count != lastcount){//えんこ代入
 // Serial.println("AAD");
if(key0f == true){
    se0 = count;
}
else if(key2f == true){
  se2 = count;
}
else if(key3f == true){
  se3 = count;
}
else if(key1f == true){
  se1 = count;
}
else if(delayallc == true){
  C = count;
}
else if(delayall == true){
  B = count;
}
else if(delayc == true){
  p1 = count;
}
    clearArea(74, 11, 55, 23);
    display.setTextSize(3);
    display.setTextColor(WHITE);
    display.setCursor(74 ,11);//(x.y)
    display.println(count);
    display.display();
   // delay(50);
  }
//display.clearDisplay();
 //Serial.println(digitalRead(key3));
//Serial.println(layer);
//Serial.println("a");



}
 lastkey0 = digitalRead(key0);
 lastkey1 = digitalRead(key1);
 lastkey2 = digitalRead(key2);
 lastkey3 = digitalRead(key3);
 lastkeyl = digitalRead(keyl);//レイヤー
 //lastkeyl = digitalRead(keyl);//レイヤー
 Serial.println(count); 
  lastcount = count;
}
         
void pulse_counter() {
 // count = 0;
  if(digitalRead(A_pin) ^ digitalRead(B_pin)) { //XOR　AとBが異なっていた時にfalseそれっていたらtrue
    count++;
  } else {
    count--;
  }
  }

void clearArea(int16_t x, int16_t y, int16_t w, int16_t h) {//塗りつぶし
    display.fillRect(x, y, w, h, SSD1306_BLACK);
}




void clearArea2(int16_t x, int16_t y, int16_t w, int16_t h) {//keyの塗りつぶし
    display.fillRect(x, y, w, h, SSD1306_BLACK);
}
     

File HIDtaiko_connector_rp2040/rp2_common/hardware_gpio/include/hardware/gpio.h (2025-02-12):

/*
 * Copyright (c) 2020 Raspberry Pi (Trading) Ltd.
 *
 * SPDX-License-Identifier: BSD-3-Clause
 */

#ifndef _HARDWARE_GPIO_H
#define _HARDWARE_GPIO_H

#include "pico.h"
#include "hardware/structs/sio.h"
#include "hardware/structs/pads_bank0.h"
#include "hardware/structs/io_bank0.h"
#include "hardware/irq.h"

// PICO_CONFIG: PICO_USE_GPIO_COPROCESSOR, Enable/disable use of the GPIO coprocessor for GPIO access, type=bool, default=1, group=hardware_gpio
#if !defined(PICO_USE_GPIO_COPROCESSOR) && HAS_GPIO_COPROCESSOR
#define PICO_USE_GPIO_COPROCESSOR 1
#endif

#if PICO_USE_GPIO_COPROCESSOR
#include "hardware/gpio_coproc.h"
#endif

#ifdef __cplusplus
extern "C" {
#endif

// PICO_CONFIG: PARAM_ASSERTIONS_ENABLED_HARDWARE_GPIO, Enable/disable assertions in the hardware_gpio module, type=bool, default=0, group=hardware_gpio
#ifndef PARAM_ASSERTIONS_ENABLED_HARDWARE_GPIO
#ifdef PARAM_ASSERTIONS_ENABLED_GPIO // backwards compatibility with SDK < 2.0.0
#define PARAM_ASSERTIONS_ENABLED_HARDWARE_GPIO PARAM_ASSERTIONS_ENABLED_GPIO
#else
#define PARAM_ASSERTIONS_ENABLED_HARDWARE_GPIO 0
#endif
#endif

/** \file gpio.h
 *  \defgroup hardware_gpio hardware_gpio
 *
 * \brief General Purpose Input/Output (GPIO) API
 *
 * RP-series microcontrollers have two banks of General Purpose Input / Output (GPIO) pins, which are assigned as follows:
 * 
 * \if rp2040-specific
 * RP2040 has 30 user GPIO pins in bank 0, and 6 QSPI pins in the QSPI bank 1 (QSPI_SS, QSPI_SCLK and QSPI_SD0 to QSPI_SD3). The QSPI 
 * pins are used to execute code from an external flash device, leaving the User bank (GPIO0 to GPIO29) for the programmer to use. 
 * \endif
 * 
 * \if rp2350-specific
 * The number of GPIO pins available depends on the package. There are 30 user GPIOs in bank 0 in the QFN-60 package (RP2350A), or 48 user GPIOs 
 * in the QFN-80 package. Bank 1 contains the 6 QSPI pins and the USB DP/DM pins.
 * \endif
 *  
 * All GPIOs support digital input and output, but a subset can also be used as inputs to the chip’s Analogue to Digital
 * Converter (ADC). The allocation of GPIO pins to the ADC depends on the packaging.
 * 
 * RP2040 and RP2350 QFN-60 GPIO, ADC pins are 26-29.
 * RP2350 QFN-80, ADC pins are 40-47.
 *  
 * Each GPIO can be controlled directly by software running on the processors, or by a number of other functional blocks.
 *
 * The function allocated to each GPIO is selected by calling the \ref gpio_set_function function. \note Not all functions
 * are available on all pins.
 *
 * Each GPIO can have one function selected at a time. Likewise, each peripheral input (e.g. UART0 RX) should only be selected on
 * one _GPIO_ at a time. If the same peripheral input is connected to multiple GPIOs, the peripheral sees the logical OR of these
 * GPIO inputs. Please refer to the datasheet for more information on GPIO function select.
 *
 * ### Function Select Table
 *
 * \if rp2040_specific
 * On RP2040 the function selects are:
 *
 * | GPIO   | F1       | F2        | F3       | F4     | F5  | F6   | F7   | F8            | F9            |
 * |--------|----------|-----------|----------|--------|-----|------|------|---------------|---------------|
 * | 0      | SPI0 RX  | UART0 TX  | I2C0 SDA | PWM0 A | SIO | PIO0 | PIO1 |               | USB OVCUR DET |
 * | 1      | SPI0 CSn | UART0 RX  | I2C0 SCL | PWM0 B | SIO | PIO0 | PIO1 |               | USB VBUS DET  |
 * | 2      | SPI0 SCK | UART0 CTS | I2C1 SDA | PWM1 A | SIO | PIO0 | PIO1 |               | USB VBUS EN   |
 * | 3      | SPI0 TX  | UART0 RTS | I2C1 SCL | PWM1 B | SIO | PIO0 | PIO1 |               | USB OVCUR DET |
 * | 4      | SPI0 RX  | UART1 TX  | I2C0 SDA | PWM2 A | SIO | PIO0 | PIO1 |               | USB VBUS DET  |
 * | 5      | SPI0 CSn | UART1 RX  | I2C0 SCL | PWM2 B | SIO | PIO0 | PIO1 |               | USB VBUS EN   |
 * | 6      | SPI0 SCK | UART1 CTS | I2C1 SDA | PWM3 A | SIO | PIO0 | PIO1 |               | USB OVCUR DET |
 * | 7      | SPI0 TX  | UART1 RTS | I2C1 SCL | PWM3 B | SIO | PIO0 | PIO1 |               | USB VBUS DET  |
 * | 8      | SPI1 RX  | UART1 TX  | I2C0 SDA | PWM4 A | SIO | PIO0 | PIO1 |               | USB VBUS EN   |
 * | 9      | SPI1 CSn | UART1 RX  | I2C0 SCL | PWM4 B | SIO | PIO0 | PIO1 |               | USB OVCUR DET |
 * | 10     | SPI1 SCK | UART1 CTS | I2C1 SDA | PWM5 A | SIO | PIO0 | PIO1 |               | USB VBUS DET  |
 * | 11     | SPI1 TX  | UART1 RTS | I2C1 SCL | PWM5 B | SIO | PIO0 | PIO1 |               | USB VBUS EN   |
 * | 12     | SPI1 RX  | UART0 TX  | I2C0 SDA | PWM6 A | SIO | PIO0 | PIO1 |               | USB OVCUR DET |
 * | 13     | SPI1 CSn | UART0 RX  | I2C0 SCL | PWM6 B | SIO | PIO0 | PIO1 |               | USB VBUS DET  |
 * | 14     | SPI1 SCK | UART0 CTS | I2C1 SDA | PWM7 A | SIO | PIO0 | PIO1 |               | USB VBUS EN   |
 * | 15     | SPI1 TX  | UART0 RTS | I2C1 SCL | PWM7 B | SIO | PIO0 | PIO1 |               | USB OVCUR DET |
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

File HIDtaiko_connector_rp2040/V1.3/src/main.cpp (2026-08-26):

#include <stdio.h>
#include "pico/stdlib.h"
#include <string.h>
#include <unistd.h>
#include <cstdlib>

#include "hardware/flash.h"
#include "hardware/sync.h"
#include "hardware/irq.h"
#include "pico/bootrom.h"
#include "hardware/structs/ioqspi.h"
#include "hardware/structs/sio.h"

#include "bsp/board.h"
#include "tusb.h"
#include "usb_descriptors.h"
#include "keyboard.h"
#include "switch_input.h"
#include "switch_cfg.h"
#include "calibration_capture.h"
#include "led.h"


uint8_t usb_mode = 0;        // 0=PCキーボード 1=Switchタタコン（起動時に確定）
uint8_t usb_mode_pref = 0;   // フラッシュに保存する起動時モード
static bool sw1_open = true;  // 直近のSW1の位置。true=オープン(PC側) false=GND(Switch側)
static calibration_profile_t calibration_profile = {};
static bool calibration_profile_crc_valid = false;
static uint8_t legacy_prefix_raw[CAL_PROFILE_LEGACY_PREFIX_BYTES] = {0};
static bool profile_preserve_prefix_once = false;
static constexpr uint32_t SETTINGS_FLASH_OFFSET = 0x1F0000;

// 起動モードを決める。SW1(GPIO8)がLOWなら無条件でSwitch、
// オープン（SW1未実装の基板を含む）ならフラッシュに保存した設定に従う
static void read_mode_switch(void) {
#ifdef FORCE_SWITCH_MODE
    usb_mode = 1;
    return;
#endif
    gpio_init(8);
    gpio_set_dir(8, GPIO_IN);
    gpio_pull_up(8);
    sleep_us(100);
    sw1_open = gpio_get(8);
    usb_mode = sw1_open ? usb_mode_pref : 1;
}

static void save_setting_to_flash(void) {
    uint16_t buf16[20] = {0};
    static_assert(sizeof(buf16) == CAL_PROFILE_LEGACY_PREFIX_BYTES, "legacy flash prefix changed");
    for (int i = 0; i < 10; i++) buf16[i] = static_cast<uint16_t>(kando[i]);
    for (int i = 0; i < 4; i++) buf16[10 + i] = key_map[i];
    for (int i = 0; i < 3; i++) buf16[14 + i] = static_cast<uint16_t>(kando[10 + i]);
    buf16[17] = usb_mode_pref;
    buf16[18] = static_cast<uint16_t>(kando[13]);
    buf16[19] = static_cast<uint16_t>(kando[14]);

    static_assert(FLASH_PAGE_SIZE == CAL_PROFILE_PAGE_BYTES, "profile page must match flash program size");
    uint8_t buffer[FLASH_PAGE_SIZE];
    bool preserve_prefix = cal_profile_consume_prefix_preservation(&profile_preserve_prefix_once);
    cal_profile_build_save_page(buffer, legacy_prefix_raw, (const uint8_t *)buf16,
                                &calibration_profile, preserve_prefix);

    uint32_t ints = save_and_disable_interrupts();
    flash_range_erase(SETTINGS_FLASH_OFFSET, FLASH_SECTOR_SIZE);
    flash_range_program(SETTINGS_FLASH_OFFSET, buffer, FLASH_PAGE_SIZE);
    restore_interrupts(ints);
    if (!preserve_prefix) memcpy(legacy_prefix_raw, buf16, sizeof(legacy_prefix_raw));
    calibration_profile_crc_valid = true;
}

void load_setting_from_flash(void) {
    const uint8_t *flash_data = (const uint8_t *)(XIP_BASE + SETTINGS_FLASH_OFFSET);
    memcpy(legacy_prefix_raw, flash_data, sizeof(legacy_prefix_raw));

    uint16_t buf16[20];
    memcpy(buf16, flash_data, sizeof(buf16));

    // 未書き込みのフラッシュは 0xFFFF。そのまま入れると感度65535で一切反応しない機体になるので、
    // keyboard.h の初期値を残す。感度の上限は500程度なので 0xFFFF は保存値と衝突しない
    for (int i = 0; i < 10; i++) {
        if (buf16[i] != 0xFFFF) kando[i] = static_cast<int>(buf16[i]);
    }
    for (int i = 0; i < 4; i++) {
        uint16_t v = buf16[10 + i];
        if (v >= 4 && v <= 0xFF) key_map[i] = static_cast<uint8_t>(v);
    }
    // 旧フォーマットのフラッシュでは 0xFFFF が入るため既定値へ倒す
    uint16_t v;
    v = buf16[14]; kando[10] = (v >= 10 && v <= 200) ? v : 25;
    v = buf16[15]; kando[11] = (v <= 2) ? v : 1;
    v = buf16[16]; kando[12] = (v <= 2) ? v : 0;
    v = buf16[17]; usb_mode_pref = (v <= 1) ? (uint8_t)v : 0;
    v = buf16[18]; kando[13] = (v <= 100) ? v : 30;
    v = buf16[19]; kando[14] = (v <= 1) ? v : 0;

    // extensionが無い旧SAVEや破損時はcandidateもlegacy相当へ戻し、pairを有効にしない
    calibration_profile_crc_valid = cal_profile_decode_extension(
        &calibration_profile, flash_data + CAL_PROFILE_LEGACY_PREFIX_BYTES,
        FLASH_PAGE_SIZE - CAL_PROFILE_LEGACY_PREFIX_BYTES);
    if (!calibration_profile_crc_valid) cal_profile_from_legacy(&calibration_profile, kando);
    profile_preserve_prefix_once = false;
}


void hid_task(void);

// SAVE で起動モードが変わったときの実行予定時刻(ms)。0なら予定なし。
// 保存を先に確定させ、応答を送り切ってから列挙し直すために一拍置く
static uint32_t mode_apply_at = 0;

// 打を検出してから、そのレポートがUSBへ渡るまでの実測(µs)。
// **PCモードとSwitchモードで同じ指標を取る**のが目的。「Switchモードだけ遅い」を
// 推測でなく数字で切り分けられるようにする。両モードとも経路上は
// 「検出→即送信」のはずなので、差が出るならそこに原因がある
static uint64_t lat_hit_us = 0;   // 未送信の打の検出時刻。0なら待ちなし
static uint32_t lat_max = 0;
static uint32_t lat_cnt = 0;
static uint64_t lat_sum = 0;

// 打を検出した瞬間に呼ぶ。既に待ちがあるなら古いほうを残す（先に検出した打の遅延を測る）
static void lat_mark(void) {
    if (lat_hit_us == 0) lat_hit_us = to_us_since_boot(get_absolute_time());
}

// レポートを実際にUSBへ渡せた瞬間に呼ぶ
static void lat_done(void) {
    if (lat_hit_us == 0) return;
    uint32_t d = (uint32_t)(to_us_since_boot(get_absolute_time()) - lat_hit_us);
    lat_hit_us = 0;
    lat_sum += d;
    lat_cnt++;
    if (d > lat_max) lat_max = d;
}

static void lat_reset(void) { lat_hit_us = 0; lat_max = 0; lat_cnt = 0; lat_sum = 0; }
static uint32_t lat_avg(void) { return lat_cnt ? (uint32_t)(lat_sum / lat_cnt) : 0; }

KeyBoard keyboard;
CalibrationCapture calibration_capture;
void serial_task(void);
static void calibration_cdc_poll(void);

void tud_cdc_line_state_cb(uint8_t itf, bool dtr, bool rts)
{
    (void)itf;
    (void)dtr;
    (void)rts;
}

volatile bool data_received = false;

void tud_cdc_rx_cb(uint8_t itf) {
    data_received = true;
}

/*------------- メイン関数 -------------*/
int main(void) {
    board_init();
    led_init();                  // 起動直後に赤→緑→青。ここが光らなければLEDのハード側の問題
    load_setting_from_flash();   // usb_mode_pref を読んでからでないとモードが決まらない
    read_mode_switch();
    tusb_init();
    adc_init();
    adc_gpio_init(26);
    adc_gpio_init(27);
    adc_gpio_init(28);
    adc_gpio_init(29);
    stdio_init_all();

    while (1) {
        tud_task();
        hid_task();
        calibration_cdc_poll();
        led_update(usb_mode != 0);
        if (data_received) {
            data_received = false;
            serial_task();
        }
    }
    return 0;
}

//-----------------------USB-----------------------
static char serial_line_buf[128] = {0};
static int serial_line_pos = 0;

// ファーム更新モードへ入る。ホストに切断と見なさせてからブートROMへ渡す。
// いきなり reset_usb_boot するとホストが古いデバイスノードを掴んだままになり、
// RPI-RP2 として列挙し直されないことがある。モード切替(apply_usb_mode)と同じ手順。
// シリアルのBOOTとHIDの0x08(BOOT)の両方から呼ぶ
static void enter_bootrom(void) {
    if (calibration_capture.busy()) calibration_capture.abort();
    led_boot_marker();      // ここまで来たことが実機に残る（led.h のコメント参照）
    tud_disconnect();
    sleep_ms(100);
    reset_usb_boot(0, 0);   // この関数から戻らない
}
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

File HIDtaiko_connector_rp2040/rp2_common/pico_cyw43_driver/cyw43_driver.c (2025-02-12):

/*
 * Copyright (c) 2022 Raspberry Pi (Trading) Ltd.
 *
 * SPDX-License-Identifier: BSD-3-Clause
 */

#include "hardware/gpio.h"
#include "hardware/irq.h"
#include "pico/unique_id.h"
#include "cyw43.h"
#include "pico/cyw43_driver.h"
#include "pico/async_context.h"

#ifndef CYW43_GPIO_IRQ_HANDLER_PRIORITY
#define CYW43_GPIO_IRQ_HANDLER_PRIORITY 0x40
#endif

#ifndef CYW43_SLEEP_CHECK_MS
#define CYW43_SLEEP_CHECK_MS 50
#endif

static async_context_t *cyw43_async_context;

static void cyw43_sleep_timeout_reached(async_context_t *context, async_at_time_worker_t *worker);
static void cyw43_do_poll(async_context_t *context, async_when_pending_worker_t *worker);

static async_at_time_worker_t sleep_timeout_worker = {
        .do_work = cyw43_sleep_timeout_reached
};

static async_when_pending_worker_t cyw43_poll_worker = {
        .do_work = cyw43_do_poll
};

static void cyw43_set_irq_enabled(bool enabled) {
    gpio_set_irq_enabled(CYW43_PIN_WL_HOST_WAKE, GPIO_IRQ_LEVEL_HIGH, enabled);
}

// GPIO interrupt handler to tell us there's cyw43 has work to do
static void cyw43_gpio_irq_handler(void)
{
    uint32_t events = gpio_get_irq_event_mask(CYW43_PIN_WL_HOST_WAKE);
    if (events & GPIO_IRQ_LEVEL_HIGH) {
        // As we use a high level interrupt, it will go off forever until it's serviced
        // So disable the interrupt until this is done. It's re-enabled again by CYW43_POST_POLL_HOOK
        // which is called at the end of cyw43_poll_func
        cyw43_set_irq_enabled(false);
        async_context_set_work_pending(cyw43_async_context, &cyw43_poll_worker);
    }
}

uint32_t cyw43_irq_init(__unused void *param) {
#ifndef NDEBUG
    assert(get_core_num() == async_context_core_num(cyw43_async_context));
#endif
    gpio_add_raw_irq_handler_with_order_priority(CYW43_PIN_WL_HOST_WAKE, cyw43_gpio_irq_handler, CYW43_GPIO_IRQ_HANDLER_PRIORITY);
    cyw43_set_irq_enabled(true);
    irq_set_enabled(IO_IRQ_BANK0, true);
    return 0;
}

uint32_t cyw43_irq_deinit(__unused void *param) {
#ifndef NDEBUG
    assert(get_core_num() == async_context_core_num(cyw43_async_context));
#endif
    gpio_remove_raw_irq_handler(CYW43_PIN_WL_HOST_WAKE, cyw43_gpio_irq_handler);
    cyw43_set_irq_enabled(false);
    return 0;
}

void cyw43_post_poll_hook(void) {
#ifndef NDEBUG
    assert(get_core_num() == async_context_core_num(cyw43_async_context));
#endif
    cyw43_set_irq_enabled(true);
}

void cyw43_schedule_internal_poll_dispatch(__unused void (*func)(void)) {
    assert(func == cyw43_poll);
    async_context_set_work_pending(cyw43_async_context, &cyw43_poll_worker);
}

static void cyw43_do_poll(async_context_t *context, __unused async_when_pending_worker_t *worker) {
#ifndef NDEBUG
    assert(get_core_num() == async_context_core_num(cyw43_async_context));
#endif
    if (cyw43_poll) {
        if (cyw43_sleep > 0) {
            cyw43_sleep--;
        }
        cyw43_poll();
        if (cyw43_sleep) {
            async_context_add_at_time_worker_in_ms(context, &sleep_timeout_worker, CYW43_SLEEP_CHECK_MS);
        } else {
            async_context_remove_at_time_worker(context, &sleep_timeout_worker);
        }
    }
}

static void cyw43_sleep_timeout_reached(async_context_t *context, __unused async_at_time_worker_t *worker) {
    assert(context == cyw43_async_context);
    assert(worker == &sleep_timeout_worker);
    async_context_set_work_pending(context, &cyw43_poll_worker);
}

bool cyw43_driver_init(async_context_t *context) {
    cyw43_init(&cyw43_state);
    cyw43_async_context = context;
    // we need the IRQ to be on the same core as the context, because we need to be able to enable/disable the IRQ
    // from there later
    async_context_execute_sync(context, cyw43_irq_init, NULL);
    async_context_add_when_pending_worker(context, &cyw43_poll_worker);
    return true;
}

void cyw43_driver_deinit(async_context_t *context) {
    assert(context == cyw43_async_context);
    async_context_remove_at_time_worker(context, &sleep_timeout_worker);
    async_context_remove_when_pending_worker(context, &cyw43_poll_worker);
    // the IRQ IS on the same core as the context, so must be de-initialized there
    async_context_execute_sync(context, cyw43_irq_deinit, NULL);
    cyw43_deinit(&cyw43_state);
    cyw43_async_context = NULL;
}

// todo maybe add an #ifdef in cyw43_driver
uint32_t storage_read_blocks(__unused uint8_t *dest, __unused uint32_t block_num, __unused uint32_t num_blocks) {
    // shouldn't be used
    panic_unsupported();
}

// Generate a mac address if one is not set in otp
void __attribute__((weak)) cyw43_hal_generate_laa_mac(__unused int idx, uint8_t buf[6]) {
    CYW43_DEBUG("Warning. No mac in otp. Generating mac from board id\n");
    pico_unique_board_id_t board_id;
    pico_get_unique_board_id(&board_id);
    memcpy(buf, &board_id.id[2], 6);
    buf[0] &= (uint8_t)~0x1; // unicast
    buf[0] |= 0x2; // locally administered
}

// Return mac address
void cyw43_hal_get_mac(__unused int idx, uint8_t buf[6]) {
    // The mac should come from cyw43 otp.
    // This is loaded into the state after the driver is initialised
    // cyw43_hal_generate_laa_mac is called by the driver to generate a mac if otp is not set
    memcpy(buf, cyw43_state.mac, 6);
}

// Prevent background processing in pensv and access by the other core
// These methods are called in pensv context and on either core
// They can be called recursively
void cyw43_thread_enter(void) {
    async_context_acquire_lock_blocking(cyw43_async_context);
}

void cyw43_thread_exit(void) {
    async_context_release_lock(cyw43_async_context);
}

#ifndef NDEBUG
void cyw43_thread_lock_check(void) {
    async_context_lock_check(cyw43_async_context);
}
#endif

void cyw43_await_background_or_timeout_us(uint32_t timeout_us) {
    if (__get_current_exception() > 0) {
        async_context_wait_until(cyw43_async_context, make_timeout_time_us(timeout_us));
        return;
    }
    async_context_wait_for_work_until(cyw43_async_context, make_timeout_time_us(timeout_us));
}

void cyw43_delay_ms(uint32_t ms) {
    async_context_wait_until(cyw43_async_context, make_timeout_time_ms(ms));
}

void cyw43_delay_us(uint32_t us) {
    async_context_wait_until(cyw43_async_context, make_timeout_time_us(us));
}

#if !CYW43_LWIP
static void no_lwip_fail() {
    panic("cyw43 has no ethernet interface");
}
void __attribute__((weak)) cyw43_cb_tcpip_init(cyw43_t *self, int itf) {
}
void __attribute__((weak)) cyw43_cb_tcpip_deinit(cyw43_t *self, int itf) {
}
void __attribute__((weak)) cyw43_cb_tcpip_set_link_up(cyw43_t *self, int itf) {
    no_lwip_fail();
}
void __attribute__((weak)) cyw43_cb_tcpip_set_link_down(cyw43_t *self, int itf) {
    no_lwip_fail();
}
void __attribute__((weak)) cyw43_cb_process_ethernet(void *cb_data, int itf, size_t len, const uint8_t *buf) {
    no_lwip_fail();
}
#endif

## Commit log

2023-09-24 最初のコミット
2023-10-15 Update sketch_hidtaiko.ino
    感度調節やdelayの調節をしやすくし、ドキムネの連打が1100くらい入ります
2023-10-29 Add files via upload
    swにも対応したhidtaiko接続器のコードです。開発中のため不具合があります。
2023-11-05 テストです。
    [connector_case.stl]
2024-02-14 connector case sketch
    [case.stl, hidtaiko.kicad_pcb]
2024-06-02 2.0接続器
2024-06-02 2.0接続器完成
2024-12-12 ino and kicad file changes
    [hidtaiko ver1.3.kicad_pcb, hidtaiko ver1.3.kicad_sch]
2025-02-12 rp2040接続器の追加
    [case.stl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]
2025-02-14 READMEの更新
    [case.stl, case_rp.stl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]
2025-02-14 修正README.md
2025-02-15 READMEの編集
2025-02-15 修正 README.md
2025-02-15 original_uf2の追加
2025-02-17 シリアル通信の感度の数値の上限アップ
2025-03-22 arduino接続器のweb感度変更機能を追加(テスト)
2025-04-16 rp2040 多重防止機能追加
2025-04-19 面を叩いた時縁の入力を受け付けない時間の追加
2025-05-05 h delayの修正
2025-05-17 RP2040ver1.1の追加、readmeの追加、センサ説明の追加
    [0.2.stl, 0.4.stl, 0.6.stl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]
2025-05-19 センサ制作手順の追加
2025-05-19 readme 修正
2025-06-02 rp2040zero 接続器制作方法readmeno
2025-12-27 rp2040用2pキーファームウェアの追加
2026-05-21 CLAUDE.mdをgit管理対象外に追加
2026-06-06 sampling 10µs固定化・タイマースワップバグ修正・キーマッピングをD/F/J/Kに変更
    - keyboard.h: 10µs固定周期サンプリング追加
    - keyboard.h: i=0(左縁)とi=1(左面)のtimer_face/timer_edge割り当てが逆になっていたバグを修正
    - keyboard.h: キーマッピングをC/X/N/MからD/F/J/Kに変更
    - keyboard.h: コードクリーンアップ（未使用変数・コメント削除）
    - main.cpp: コードクリーンアップ（重複include・未使用変数削除、serial_Mode配列を単一boolに）
    - src/CMakeLists.txt: 別ユーザーの絶対パス参照と重複pico_sdk_init()を削除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
    [main.cpp]
2026-06-09 web UI追加・ファームウェア改善・README更新
    - docs/: 感度調整WebUI（V1.1/V1.2）を追加
    - V1.2: 簡単/高度モード切替、iOS式EN/JPトグル、遅延スライダー改善、キー配置変更UI
    - V1.1: 保存ボタン対応、iOS式言語トグルに統一
    - 共通: 説明欄の初期折りたたみ、ファームウェアアップデート案内
    - RP2040ファームウェア: kando配列再定義・シリアル通信バグ修正・ADC初期化修正
    - README.md/README_EN.md: 説明を更新
    - .gitignore: ルートに追加
    - SNS,shop/: 関連リンク追加
    [main.cpp]
2026-06-09 不要ファイルをgit管理から除外
    SNS,shop/ arduino_minimum drumhead HIDtaiko.code-workspace を追跡解除。
    各フォルダは .gitignore に記載済み。
    [0.2.stl, 0.4.stl, 0.6.stl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]
2026-06-09 V1.2ファームウェアをoriginal_uf2に追加
2026-06-09 ファームウェア手順改善・README感度サイトリンク更新・original_uf2整理
    - docs/v12.html: FW手順にBOOTボタン写真追加・step2をリリースページDLに変更・リリースリンクをボタン化
    - docs/main.css: .fw-release-link スタイル追加
    - docs/img: boot_button.jpg / fw_release.png 追加
    - README.md / README_EN.md: 感度変更サイトリンクをv12.htmlに変更
    - original_uf2: V1.1・V1.2フォルダ構成に整理
2026-06-27 @ drumhead追加(gitignore除外解除)・READMEのセンサ部品表を削除
    @
    [0.2.stl, 0.4.stl, 0.6.stl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]
2026-07-04 Fix fullsize print link
2026-08-27 Track all HIDtaiko guide versions in GA4
2026-09-14 Add GA4 conversion events and turn index into a version hub
    - hid-events.js: shared gtag wrapper, plus automatic outbound_github
    - device_connect / settings_apply on the V1.1, V1.2 and V1.3 tools
    - firmware_flash success/error on the V1.3 flasher
    - index.html is now a version picker; the V1.1 tool moved to v11.html
    - the hub warns when the browser has neither WebSerial nor WebHID
    The wrapper is named hid-events.js because ga-events.js is blocked by
    common ad blocker filter lists.
    Claude-Session: https://claude.ai/code/session_01Ned6nCu8cy9zeuBM5u7q7Z
2026-09-14 Send firmware_flash_success so the key event can be counted
    GA4 key events are keyed on the event name alone, so the success case
    needs its own name alongside the parameterised firmware_flash.
    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
2026-09-22 Add a Switch-focused V1.3 banner to the V1.2 page
    The V1.2 page draws the most views (502 of 1026 over 28 days) but bounces
    at 50.6%, against 28.3% on V1.3. Put the upgrade above the header and
    count the clicks as banner_to_v13.
    Claude-Session: https://claude.ai/code/session_01NoyH5tdDZNfQcDsjzPF8Xa
2026-10-15 v13: Let Android Chrome change settings over WebUSB (CDC)
    Android Chrome has no WebHID, so the connect button falls back to WebUSB,
    claims the PC-mode CDC interface and translates the HID config commands into
    the legacy text commands (SENS/MODE/KEY/SAVE/GETS/GETK/STAT). PC mode only;
    kando[15] is not sent because the CDC SENS command does not accept it.
    Claude-Session: https://claude.ai/code/session_01TxVNw1KFGFY63t245Yjinb
2026-10-28 docs: キットの組み立て説明書PDFを公開
    Claude-Session: https://claude.ai/code/session_01RdusKuUr5shbAStoEiLmuT
